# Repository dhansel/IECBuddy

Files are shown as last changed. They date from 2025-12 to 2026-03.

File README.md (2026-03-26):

# IECBuddy

IECBuddy is a USB plug-in for the [C64 RAD Expansion Unit](https://github.com/frntc/RAD), giving the RAD
access to the C64's IEC bus. The IECBuddy is based on my [IECDevice](https://github.com/dhansel/IECDevice)
and [VDrive](https://github.com/dhansel/VDrive) libraries, allowing the RAD to support various disk image 
formats (D64, G64, D71, D81) and fast-load protocols (JiffyDos, Epyx FastLoad, Final Cartridge 3, Action Replay 6,
DolphinDos and SpeedDos). Additionally, the IECBuddy acts as a virtual printer. Printed content can be viewed
on the C64 screen from within the RAD menu.

<br>
  <div align="center">
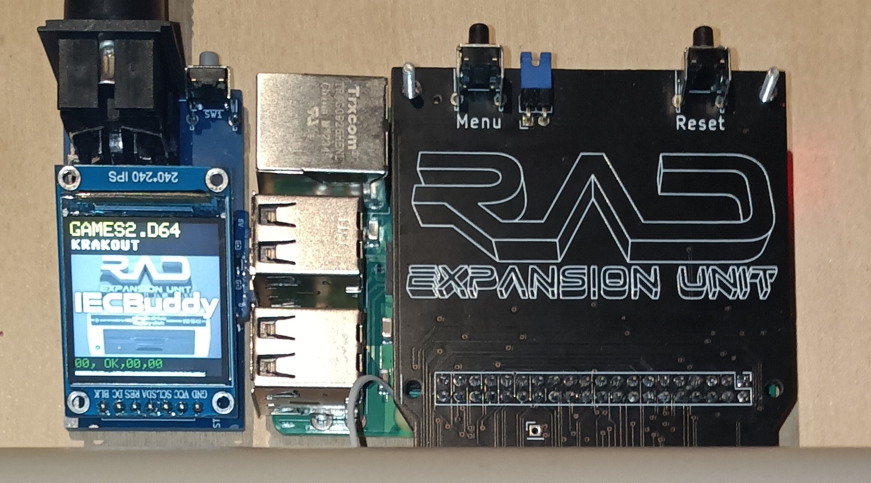
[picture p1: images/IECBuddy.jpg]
  
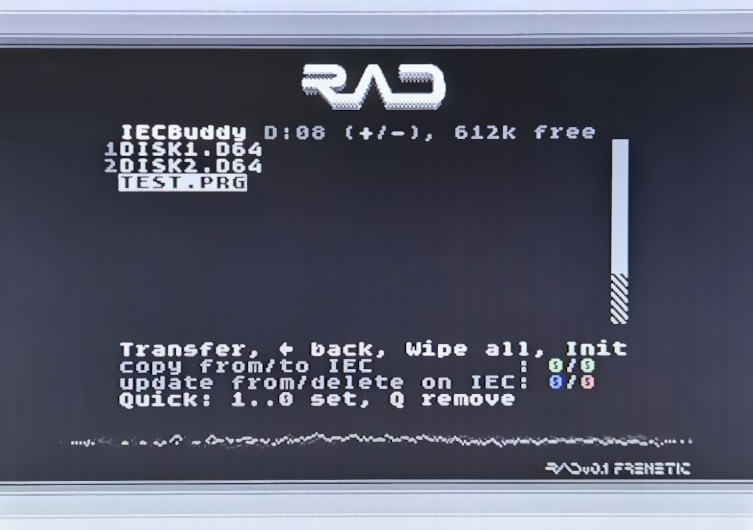
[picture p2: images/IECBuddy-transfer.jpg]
  
  </div>
<br>

The IECBuddy comes in four different variants, with differing amounts of components and build effort required:
  * [Barebones](IECBuddy-Barebones) (no PCB, use any RP2040/RP235x module)
  * [Micro](IECBuddy-Micro) (like Barebones but with a PCB and disk change button, requires a RP module pin-compatible with RP2040-One)
  * [Mini](IECBuddy-Mini) (like Micro but with a display and better bus interface, requires a RP module pin-compatible with RP2040-One)
  * [Max](IECBuddy-Max) (like Mini but with parallel cable connector, requires a RP module pin-compatible with Raspberry Pi Pico)

Of course a myriad versions of RP2040 and R235x modules exist. The PCBs for the IECBuddy Micro and Mini variants assume the pinout
of a [RP2040-One](https://www.amazon.com/RP2040-One-Pico-Like-Raspberry-Dual-Core-Processor/dp/B0BMM7SS99). The PCB for the
IECBuddy Max variant assumes the pinout of a Raspberry Pi Pico. The IECBuddy Barebones variant can work with any RP2040 or RP235x module.

To keep things a bit more succinct, in the folling "RP module" stands for "RP2040/RP235x module".

If you have a module with a pinout matching your preferred IECBuddy variant, first check if your module is listed in the UF2 table within the
[uploading the firmware](#uploading-the-firmware) section. If you cannot use one of the provided UF2 firmware files it should still
be fairly easy to [compile and upload](software/IECBuddy/README.md) the firmware yourself.

The IECBuddy stores files and disk images in the RP module's flash memory. One MB of flash memory is used for the
firmware itself, the remainder can be used for storing disk images. One MB of flash memory can hold about six D64 disk images.
Note that disk images can easily be transferred between the RAD and the IECBuddy so the IECBuddy does not need to hold all
your disk images at the same time.

The IECBuddy can plug directly into a RAD powered by a Raspberry Pi 3. If your RAD uses a Raspberry Pi Zero then 
you will need [an adapter cable](https://www.raspberrypi.com/products/micro-usb-male-to-usb-a-female-cable/) 
to connect the IECBuddy since the Zero only has a micro-USB OTG port.

To build an IECBuddy, select and build whichever variant appeals to you and then follow the instructions in the
[Uplodading the firmware](#uploading-the-firmware) section below.

## IECBuddy Barebones

The barebones variant is the simplest version, requiring no manufactured PCB. While the pictures shown here use
a [RP2040-One](https://www.amazon.com/RP2040-One-Pico-Like-Raspberry-Dual-Core-Processor/dp/B0BMM7SS99) module, any
RP module should work. Additionally you will need a Commodore [serial cable](https://www.c64-wiki.com/wiki/Serial_Port)
connector. Either solder the cable directly to the RP module or set it up on a breadboard:

<br>
  <div align="center">
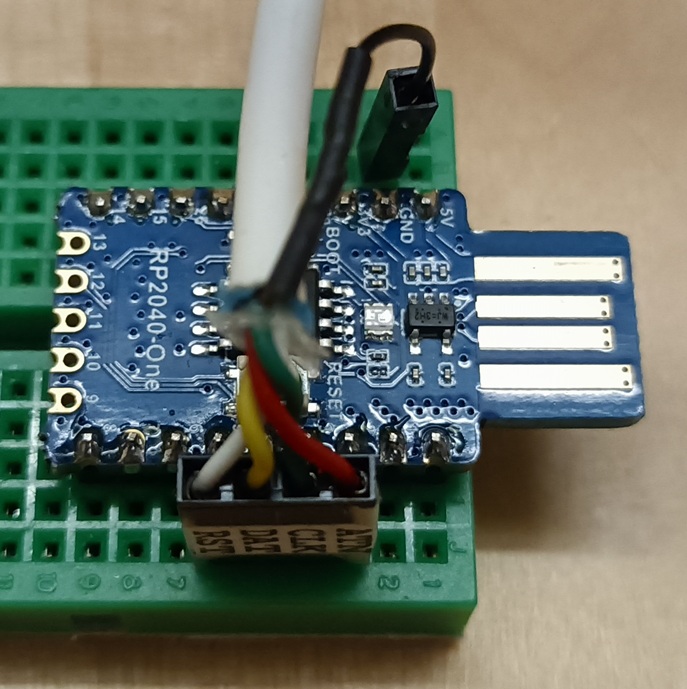
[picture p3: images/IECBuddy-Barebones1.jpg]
  
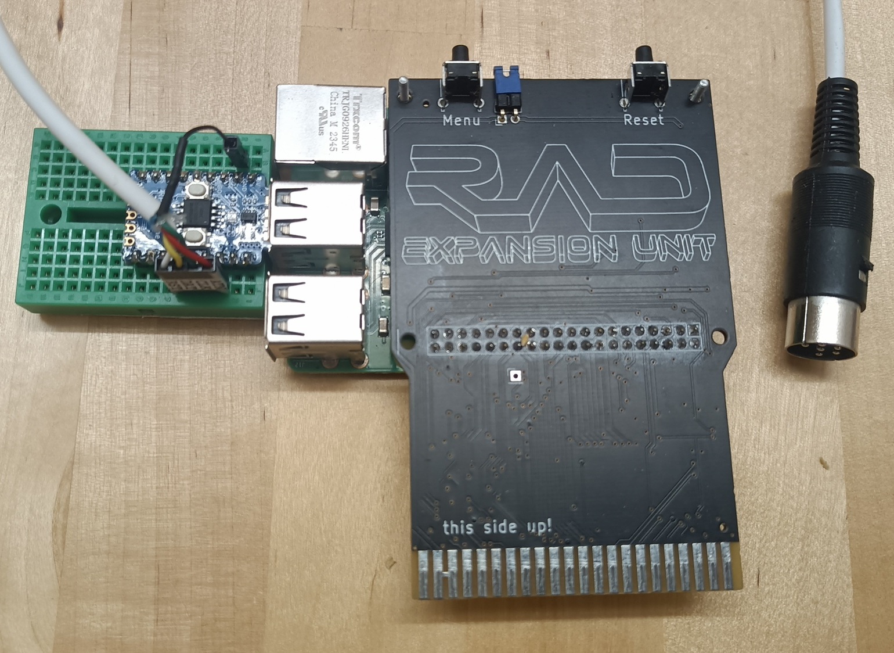
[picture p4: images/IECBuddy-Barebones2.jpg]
  
  </div>
<br>

Connect the Commodore serial cable to the RP module as follows:

IEC Bus Pin | Signal   | RP module
------------|----------|-----------
1           | SRQ      | Not connected 
2           | GND      | GND
3           | ATN      | GPIO2
4           | CLK      | GPIO3 
5           | DATA     | GPIO4 
6           | RESET    | GPIO5 

Then [upload the IECBuddy Micro firmware](#uploading-the-firmware) to the RP module and you're good to go.
Downsides are that there is no display and no "Disk Change" button.
If you would like a "Disk Change" button, simply wire a pushbutton switch between pins GND and GPIO8 on the RP module.

Note that this connects the 5V IEC bus lines directly to the RP module inputs. There are varying
opinions online on whether or not this can damage the RP and/or whether the RP is
capable of properly driving the IEC bus lines (especially when multiple devices are connected).
In my testing I have not had any problems, even with multiple other devices connected. YMMV.

If you would prefer proper voltage conversion and line drivers then use the "Mini" version below.

## IECBuddy Micro

<br>
  <div align="center">
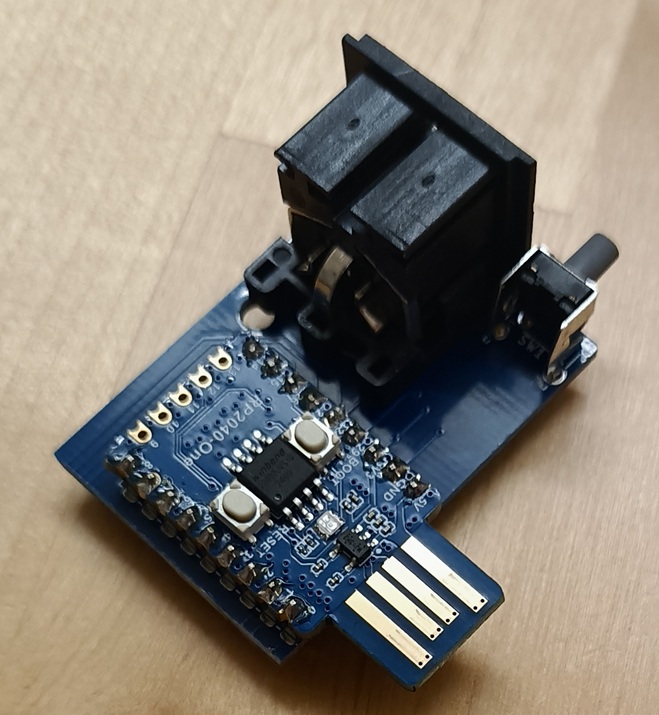
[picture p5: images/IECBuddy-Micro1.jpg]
  
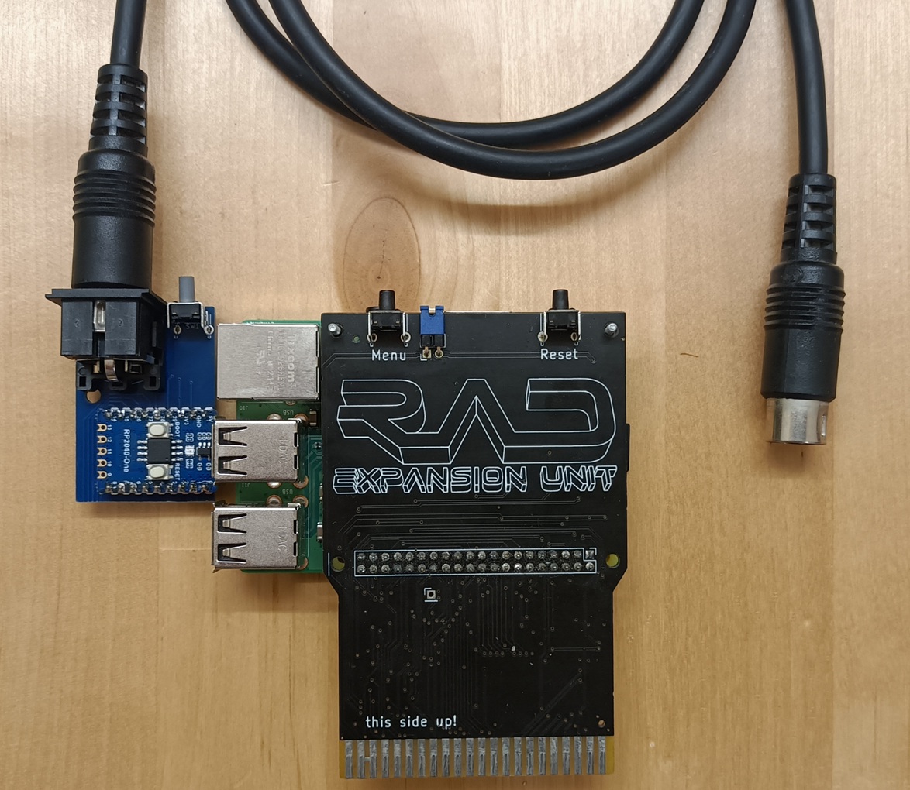
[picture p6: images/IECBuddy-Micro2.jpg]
  
  </div>
<br>

If you would like a somewhat cleaner and more permanent build but still want to go with a very small
footprint and minimal component count, use the "IECBuddy Micro" variant. This PCB requires a RP
module that is pin-compatible with the RP2040-One. Check the [Uplodading the firmware](#uploading-the-firmware) 
section below to see which RP modules are supported.

You can either solder the serial cable directly onto the board (connections are labeled on the board) or solder a 
proper IEC connector onto the board and use a standard serial cable. This also comes with
space for a pushbutton switch. No display though.

The same caveats regarding voltage conversion and line drivers apply as described in the "Barebones" section above.

A Gerber file for PCB production can be downloaded [here](https://github.com/dhansel/IECBuddy/raw/refs/heads/main/hardware/IECBuddy-micro-gerber.zip).<br>
A PDF file with the schematics is available [here](https://github.com/dhansel/IECBuddy/raw/refs/heads/main/hardware/IECBuddy-micro-schematic.pdf).<br>
KiCad files for the board are [here](hardware/IECBuddy-micro).

You will need the following components (the given links are just suggestions, I do not get any kickbacks for them).

Designator | Component 
-----------|-----------
U1         | [RP2040-One](https://www.amazon.com/RP2040-One-Pico-Like-Raspberry-Dual-Core-Processor/dp/B0BMM7SS99)
SW1        | [Pushbutton Switch](https://www.digikey.com/en/products/detail/c-k/PTS645VH58-2-LFS/1146783)
IEC1       | [IEC Bus Connector (6 Pin)](https://www.aliexpress.us/item/3256807108500271.html)

You can skip the IEC1 connector if you solder the serial cable directly to the board (connections on the board are labeled).

## IECBuddy Mini

  <div align="center">
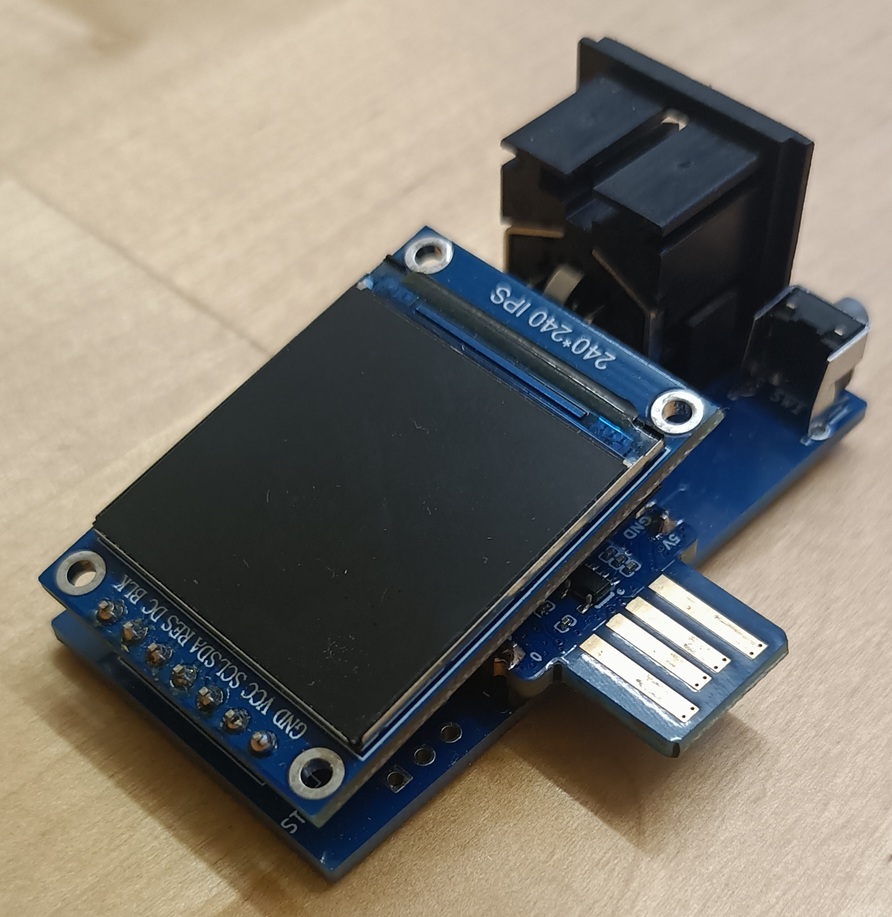
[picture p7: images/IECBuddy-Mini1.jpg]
  
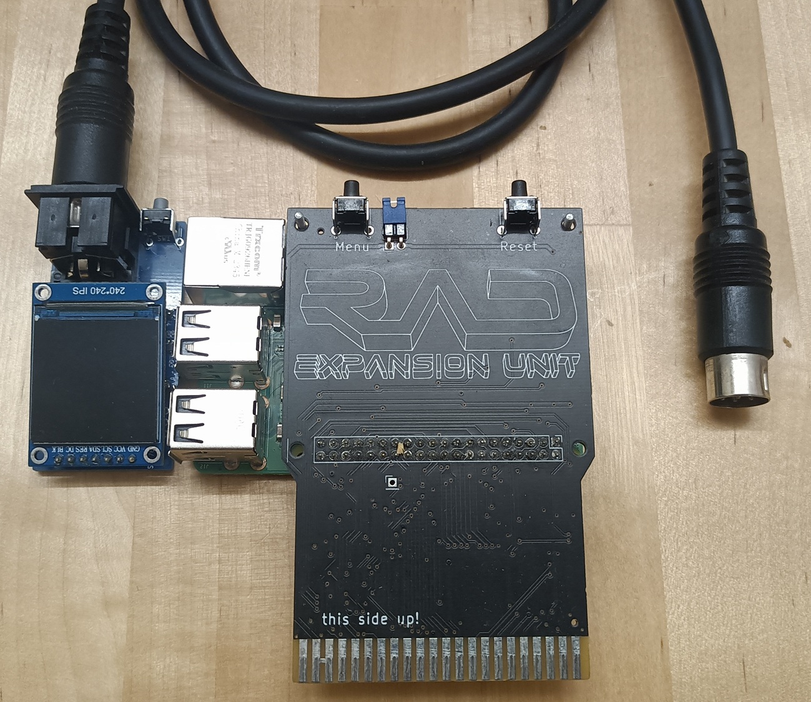
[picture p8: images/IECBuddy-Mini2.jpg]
  
  </div>

The Mini variant is slightly larger than the Micro version and requires more components besides
the RP module. As a result it comes with the following features that are not present in the smaller versions:

First, it has space and connections on the PCB for a [1.3" TFT display](https://www.aliexpress.us/item/3256805899270213.html).
The display shows the currently mounted disk image as well as disk status and progress bars while loading.

Second, it uses 7406 and 74LVC04 ICs for voltage conversion and properly interfacing with and driving the Commodore IEC bus lines.
This is very similar to the way original hardware (like the 1541) interfaces to the IEC bus. It also protects the RP
from the possible overcurrent and overvoltage conditions described in the "Barebones" section above.

Like the Micro variant, this PCB requires a RP module that is pin-compatible with the RP2040-One. 
Check the [Uplodading the firmware](#uploading-the-firmware) section below to see which RP modules are supported.

A Gerber file for PCB production can be downloaded [here](https://github.com/dhansel/IECBuddy/raw/refs/heads/main/hardware/IECBuddy-mini-gerber.zip).<br>
A PDF file with the schematics is available [here](https://github.com/dhansel/IECBuddy/raw/refs/heads/main/hardware/IECBuddy-mini-schematic.pdf).<br>
KiCad files for the board are [here](hardware/IECBuddy-mini).

You will need the following components (the given links are just suggestions, I do not get any kickbacks for them).

Designator | Component 
-----------|-----------
R1,R2,R3,R4| [Resistor 1kOhm SMD0805](https://www.digikey.com/en/products/detail/stackpole-electronics-inc/RMCF0805FT1K00/1760090)
C1,C2      | [Ceramic Capacitor 100nF SMD0805](https://www.digikey.com/en/products/detail/kyocera-avx/KGM21NR71H104KT/563505)
U1         | [RP2040-One](https://www.amazon.com/RP2040-One-Pico-Like-Raspberry-Dual-Core-Processor/dp/B0BMM7SS99)
U2         | [74LVC04AD SOIC](https://www.digikey.com/en/products/detail/nexperia-usa-inc/74LVC04AD-118/946673)
U3         | [7406DR SOIC](https://www.digikey.com/en/products/detail/texas-instruments/SN7406DR/276661)
SW1        | [Pushbutton Switch](https://www.digikey.com/en/products/detail/c-k/PTS645VH58-2-LFS/1146783)
ST7789     | [TFT Display](https://www.aliexpress.us/item/3256805899270213.html)
IEC1       | [IEC Bus Connector (6 Pin)](https://www.aliexpress.us/item/3256807108500271.html)

Various components can be left out if desired:
  * You can leave out the IEC1 connector if you solder the serial cable directly to the board (connections on the board are labeled).
  * You can leave out the ST7789 display if you don't want a display.
  * If you don't want to use the IEC bus driver ICs then you can place solder on the JP1-JP5 solder jumpers and leave out R1-R4, C1, C2, U2 and U3 (in this case use the IECBuddyMicro.uf2 firmware).

I recommend uploading the firmware **before** soldering on the display. The display sits on top of the RP module, which
makes accessing the "Boot" button (required for firmware upload) tricky - still possible, but a bit fiddly.

## IECBuddy Max

The IECBuddy Max variant has a much larger PCB layout and uses a Raspberry Pi Pico (version 1 or 2).
It has all the features of the Mini version and additionally a second IEC port for daisy-chaining 
and a connector for a parallel cable to be used with Dolphin Dos and Speed Dos.
Descriptions on how to make a compatible parallel cable and user port connector can be found in
various places over the internet, for example
[here](https://github.com/dhansel/IECDevice/tree/main/hardware#user-port-breakout-board),
[here](https://github.com/svenpetersen1965/1541-parallel-adapter-SpeedDOS)
or [here](https://github.com/FraEgg/commodore-1541-parallel-port-adapter-c64-c128-speeddos-dolphindos)

  <div align="center">
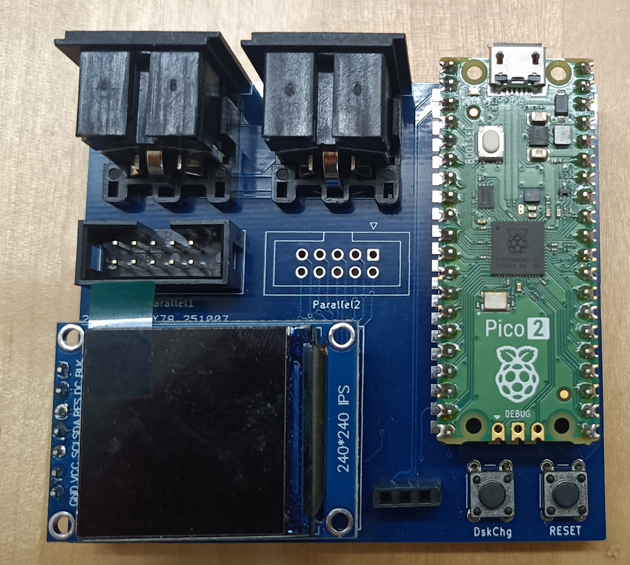
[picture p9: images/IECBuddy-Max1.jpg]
  
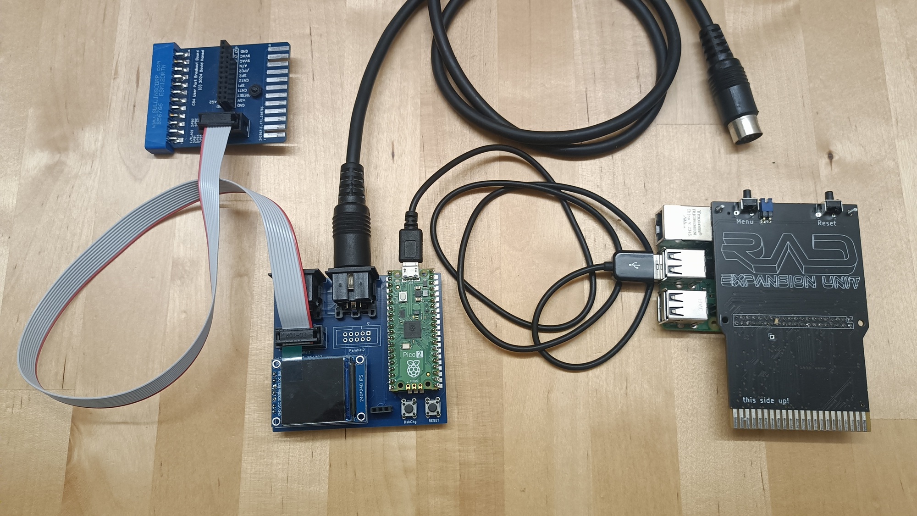
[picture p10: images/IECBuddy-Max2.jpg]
  
  </div>

A Gerber file for PCB production can be downloaded [here](https://github.com/dhansel/IECBuddy/raw/refs/heads/main/hardware/IECBuddy-max-gerber.zip).<br>
A PDF file with the schematics is available [here](https://github.com/dhansel/IECBuddy/raw/refs/heads/main/hardware/IECBuddy-max-schematic.pdf).<br>
KiCad files for the board are [here](hardware/IECBuddy-max).

This PCB requires a RP module that is pin-compatible with the Raspberry Pi Pico. 
Check the [Uplodading the firmware](#uploading-the-firmware) section below to see which RP modules are supported.

You will need the following components (the given links are just suggestions, I do not get any kickbacks for them).

Designator | Component 
-----------|-----------
R1,R2,R3,R4| [Resistor 1kOhm SMD0805](https://www.digikey.com/en/products/detail/stackpole-electronics-inc/RMCF0805FT1K00/1760090)
C1,C2,C3   | [Ceramic Capacitor 100nF SMD0805](https://www.digikey.com/en/products/detail/kyocera-avx/KGM21NR71H104KT/563505)
U1         | [Raspberry Pi Pico](https://www.microcenter.com/product/661033/raspberry-pi-pico-microcontroller-development-board)
U2         | [74CBTD3861DW](https://www.digikey.com/en/products/detail/texas-instruments/SN74CBTD3861DW/378015)
U3         | [74LVC04AD SOIC](https://www.digikey.com/en/products/detail/nexperia-usa-inc/74LVC04AD-118/946673)
U4         | [7406DR SOIC](https://www.digikey.com/en/products/detail/texas-instruments/SN7406DR/276661)
Reset,DiskChg | [Pushbutton Switch](https://www.digikey.com/en/products/detail/same-sky-formerly-cui-devices-/TS02-66-60-BK-100-LCR-D/15634327)
ST7789     | [TFT Display](https://www.aliexpress.us/item/3256805899270213.html)
IEC1       | [IEC Bus Connector (6 Pin)](https://www.aliexpress.us/item/3256807108500271.html)
Parallel1, Parallel2 | [10-position IDC Connector](https://www.digikey.com/en/products/detail/on-shore-technology-inc/302-S101/2178422)

## Uploading the firmware

Pre-compiled versions of the firmware are available for all four versions of the IECBuddy and a variety of RP modules. 

If your RP module is included in the table below then programming is trivial. First, download the UF2 file appropriate for your IECBuddy variant and RP module
("---" in the table means "not supported because the RP module does not match the PCB"):

IECBuddy   | [RP2040-One](https://www.amazon.com/RP2040-One-Pico-Like-Raspberry-Dual-Core-Processor/dp/B0BMM7SS99) <br> (4MB flash) | [RP2350-One](https://www.ebay.com/itm/286217752456) <br> (4MB flash) | [TENSTAR RP2350](https://aliexpress.com/item/1005008622261552.html) <br> (16MB flash) | Pi Pico <br> (2MB flash) | Pi Pico 2 <br> (4MB flash) | [Purple Pico](https://de.aliexpress.com/item/1005005594351599.html) <br> (16MB flash)
-----------|------------|------------|-------------------|----------------|---------------------|---------------------
Barebones  | [UF2](https://github.com/dhansel/IECBuddy/raw/refs/heads/main/software/IECBuddyMicro2040One.uf2) | [UF2](https://github.com/dhansel/IECBuddy/raw/refs/heads/main/software/IECBuddyMicro2350One.uf2) | [UF2](https://github.com/dhansel/IECBuddy/raw/refs/heads/main/software/IECBuddyMicroTenstar2350.uf2) | [UF2](https://github.com/dhansel/IECBuddy/raw/refs/heads/main/software/IECBuddyMicroPico1.uf2) | [UF2](https://github.com/dhansel/IECBuddy/raw/refs/heads/main/software/IECBuddyMicroPico2.uf2) | [UF2](https://github.com/dhansel/IECBuddy/raw/refs/heads/main/software/IECBuddyMicroPurplePico.uf2)
Micro      | [UF2](https://github.com/dhansel/IECBuddy/raw/refs/heads/main/software/IECBuddyMicro2040One.uf2) | [UF2](https://github.com/dhansel/IECBuddy/raw/refs/heads/main/software/IECBuddyMicro2350One.uf2) | [UF2](https://github.com/dhansel/IECBuddy/raw/refs/heads/main/software/IECBuddyMicroTenstar2350.uf2) | --- | --- | ---
Mini       | [UF2](https://github.com/dhansel/IECBuddy/raw/refs/heads/main/software/IECBuddyMini2040One.uf2) | [UF2](https://github.com/dhansel/IECBuddy/raw/refs/heads/main/software/IECBuddyMini2350One.uf2)  | [UF2](https://github.com/dhansel/IECBuddy/raw/refs/heads/main/software/IECBuddyMiniTenstar2350.uf2)  | --- | --- | ---
Max        | --- | --- | --- | [UF2](https://github.com/dhansel/IECBuddy/raw/refs/heads/main/software/IECBuddyMaxPico1.uf2) | [UF2](https://github.com/dhansel/IECBuddy/raw/refs/heads/main/software/IECBuddyMaxPico2.uf2) | ---

Then:
  1) Connect the USB connector of the RP module to your computer in "boot" mode. This can be done in two ways:
     - Make the connection to the computer **while holding down the "Boot" button on the device**. Note that this can be tricky
       for the Mini version if you have already soldered the display since the display obstructs access to the RP2040-One.
     - Just connect the RP module without holding the "Boot" button down. This will register a new serial (COM) port on your computer.
       Download [SKTool.exe](https://github.com/dhansel/IECBuddy/raw/refs/heads/main/software/SKTool/SKTool.exe) and run it with the following parameters: `SKTool -p COMx boot` (where COMx is the new COM port).
       Alternatively, start a terminal program (e.g. TeraTerm, Putty or even the serial monitor in the Arduino IDE) and connect
       to the new COM port with a baud rate of 1200.
     As a result of either of these, your computer should now show a new external drive.
  2) Copy the downloaded UF2 file to the root directory of the new drive.
  3) Disconnect the RP module from your computer.

If your RP module is not included in the table above and/or you would like to compile the firmware yourself, instructions can be found [here](software/IECBuddy/README.md). 

## Usage

When it is connected to the RAD (via USB) and C64 (via serial cable), the IECBuddy behaves like a disk drive.
The initial device number is 8 but can be configured from within the RAD menu system.

The IECBuddy is based on the [IECDevice library](https://github.com/dhansel/IECDevice) and therefore supports the 
same fastload protocols: JiffyDos, Epyx FastLoad, Final Cartridge 3, Action Replay 6, DolphinDos and SpeedDos.
Games that use their own fastload protocols will likely not work, the IECBuddy will report error "M-E not supported"
and the on-board LED will blink quickly (5Hz as opposed to 2Hz for a regular error).

Loading the directory shows all files and disk images currently on the IECBuddy file system. You can use "CD"
to enter and exit disk images. If you have a DOS wedge (like in JiffyDos), `@CD:GAMES.D64` will enter the GAMES.D64
Disk image, `@CD/` will exit the image and go back to the top-level directory. If you do not have a DOS wedge, 
doing a `LOAD"GAMES.D64",8` will automatically switch into the GAMES.D64 disk image and load its directory,
`LOAD"/",8` will return to the top level.

If desired, a new disk image can be created by using the "N" command, for examplem, executing `@N:GAMES2.D64`
in the top-level dierctory will create a new disk image named GAMES2.D64.

Files (either PRG files or disk images) can be copied between the IECBuddy and the RAD's SD card via the RAD menu system.
To enter the [IECBuddy submenu](https://github.com/frntc/RAD#iecbuddy-submenu) on the RAD, press "I" within the RAD main menu.

<br>
  <div align="center">
  
  </div>
<br>

The IECBuddy also emulates a printer, more specifically a STAR NL-10 printer with device number 4. The STAR NL-10 was
compatible with Commodore MPS-801 commands as well as the EPSON FX-80 command set. Much of the existing C64 software
supports either one of these (if not specifically the NL-10) and should therefore be compatible.

After printing, enter the RAD menu to see a preview of the printout and/or copy a BMP or PDF version of the printed
content to the RAD's SD card.

<br>
  <div align="center">
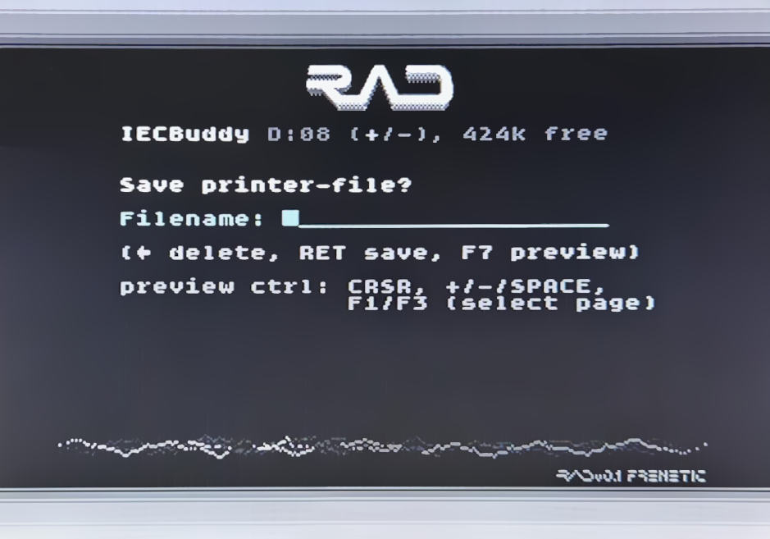
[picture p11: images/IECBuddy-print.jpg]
  
  </div>
<br>

For more information on the RAD menu structure relating to the IECBuddy see [here](https://github.com/frntc/RAD#iecbuddy-submenu).

As an alternative to copying files via the RAD menu interface you can use connect the IECBuddy to your PC 
and use [SKTool](software/SKTool) to manage the files directly.

## Firmware revisions

The following IECBuddy firmware revisions have been released:

  - **1.0** (January 26, 2026)
    - Initial release
   
  - **1.01** (March 16, 2026)
    - Support ",A" (append) file open mode in main directory
    - If a file is created in the main directory and the file has a known extension (PRG, SEQ, D64, D71, D81, G64, G71) then do not add an additional .PRG extension
    - Fixed JiffyDos protocol timing issue when transmitting EOI in single-byte protocol
    - Fixed support of "XF-" and "XF+" commands in DolphinDos

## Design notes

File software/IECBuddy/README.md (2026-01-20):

## Compiling the firmware from source

In most cases it is easiest to [simply upload the provided .uf2 files]([../../../README.md#uploading-the-firmware](https://github.com/dhansel/IECBuddy/tree/main?tab=readme-ov-file#uploading-the-firmware)) to the RP2040-One.

If you would like to compile the firmware from source then follow these steps:
  1) Download this GitHub repository.
  2) Load the "IECBuddy.ino" file from this directory in the Arduino IDE.
  3) In the Tools->Board menu, select the "Waveshare RP2040-One" board (or Raspberry Pi Pico 1 or 2 for the Max variant).
  4) In the Tools->Flash Size menu, select the following option:
     - For Waveshare RP2040-One or Raspberry Pi Pico 2: "4MB (Sketch 1MB, FS 3MB)"
     - For Raspberry Pi Pico 1: "2MB (Sketch 1MB, FS 1MB)"
     - If you are using a RP2040 clone with more flash then select the option that provides the most FS space possible, just leave 1MB for the sketch.
  6) Edit the "Pins.h" file to configure for your desired variant:
     - For the Barebones and Micro variants no changes are required
     - For the Mini or Max variants, un-comment the #defines for PIN_IEC_CLK_OUT and PIN_IEC_DATA_OUT
  7) If your build should support the ST7789 display then un-comment the PIN_ST7789_* defines. In that case you
    also need to make sure the "Adafruit GFX Library" is installed. You can compile in the display support even
    if you don't actually have a display.
  8) Plug in your RP2040-One or Pi Pico board and click the "upload" button in the Arduino IDE.

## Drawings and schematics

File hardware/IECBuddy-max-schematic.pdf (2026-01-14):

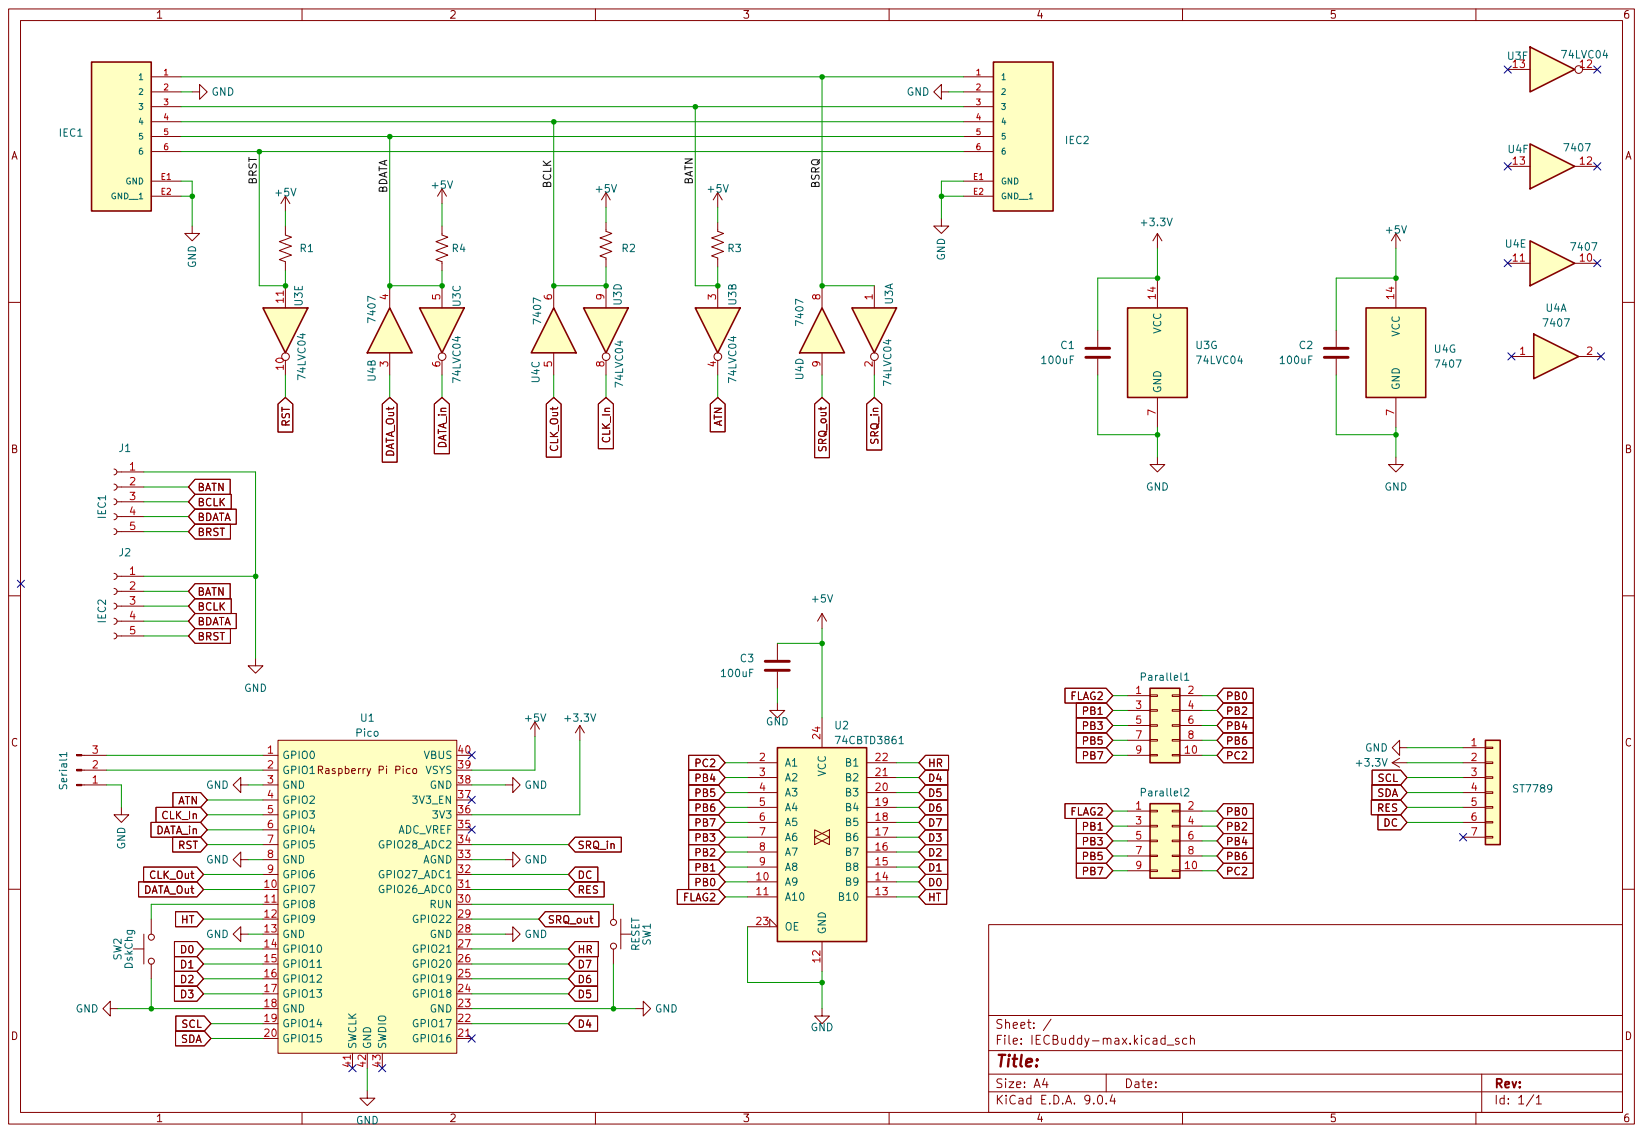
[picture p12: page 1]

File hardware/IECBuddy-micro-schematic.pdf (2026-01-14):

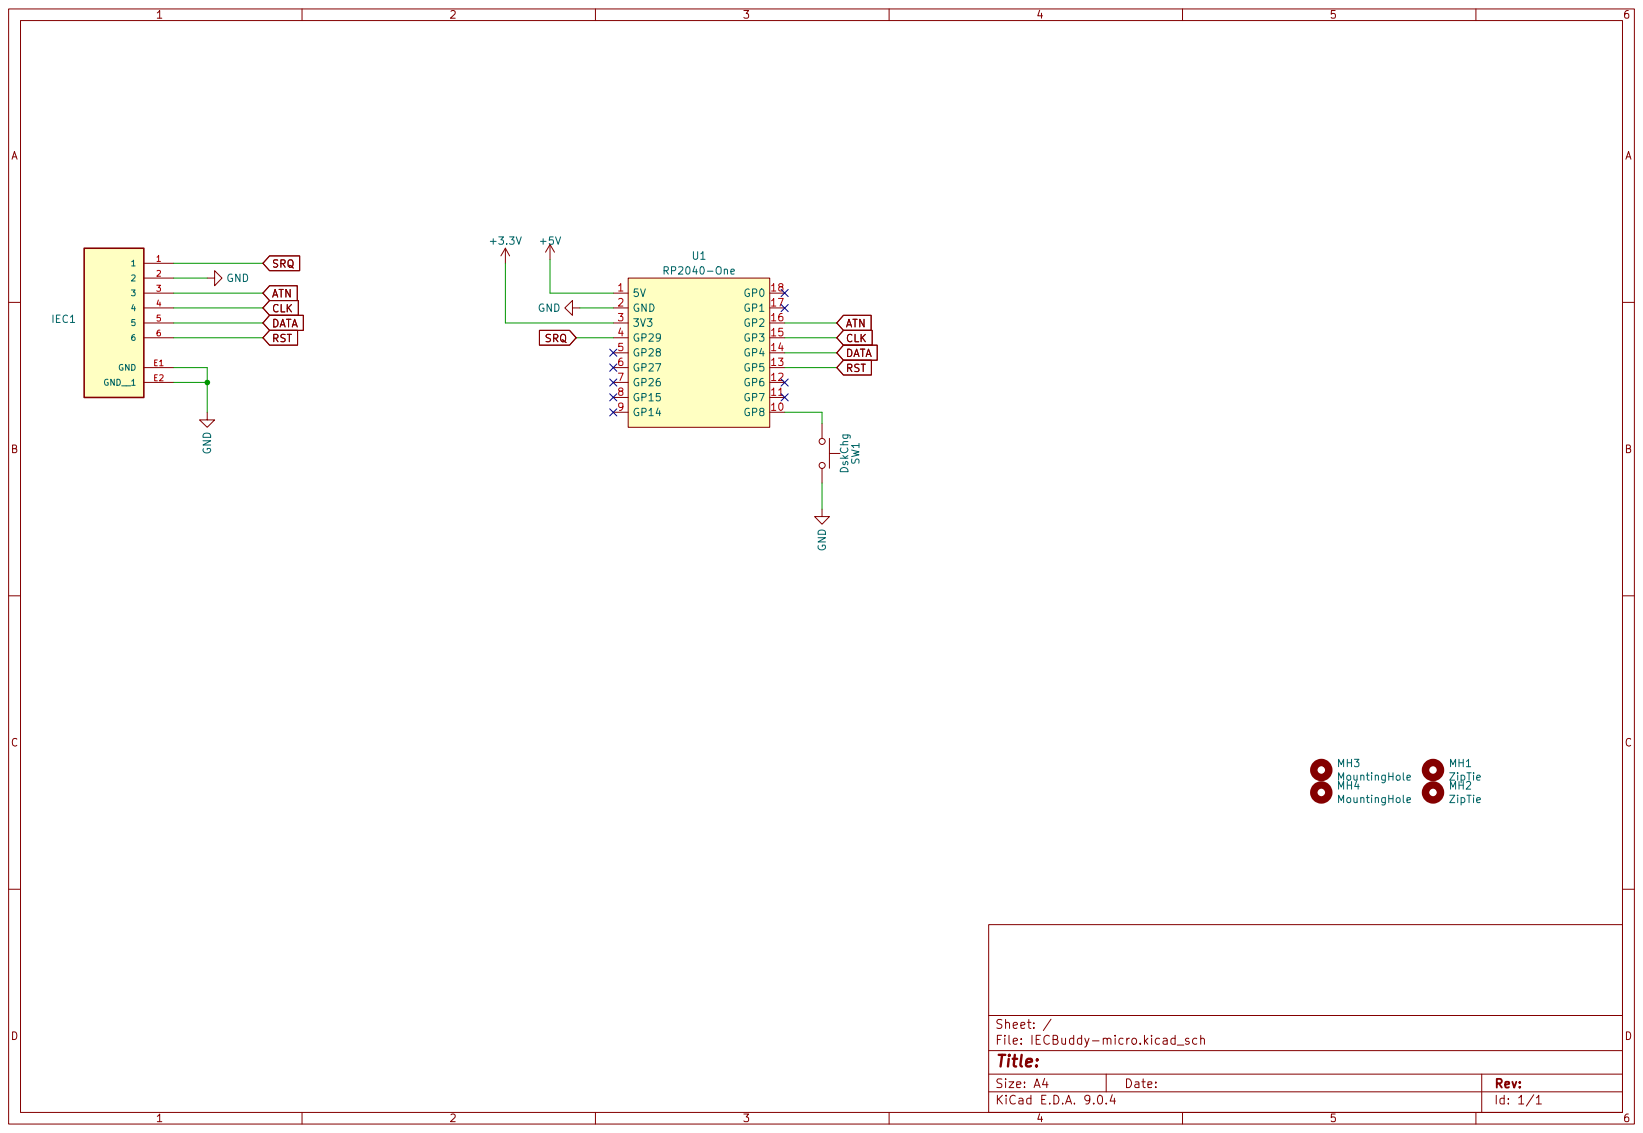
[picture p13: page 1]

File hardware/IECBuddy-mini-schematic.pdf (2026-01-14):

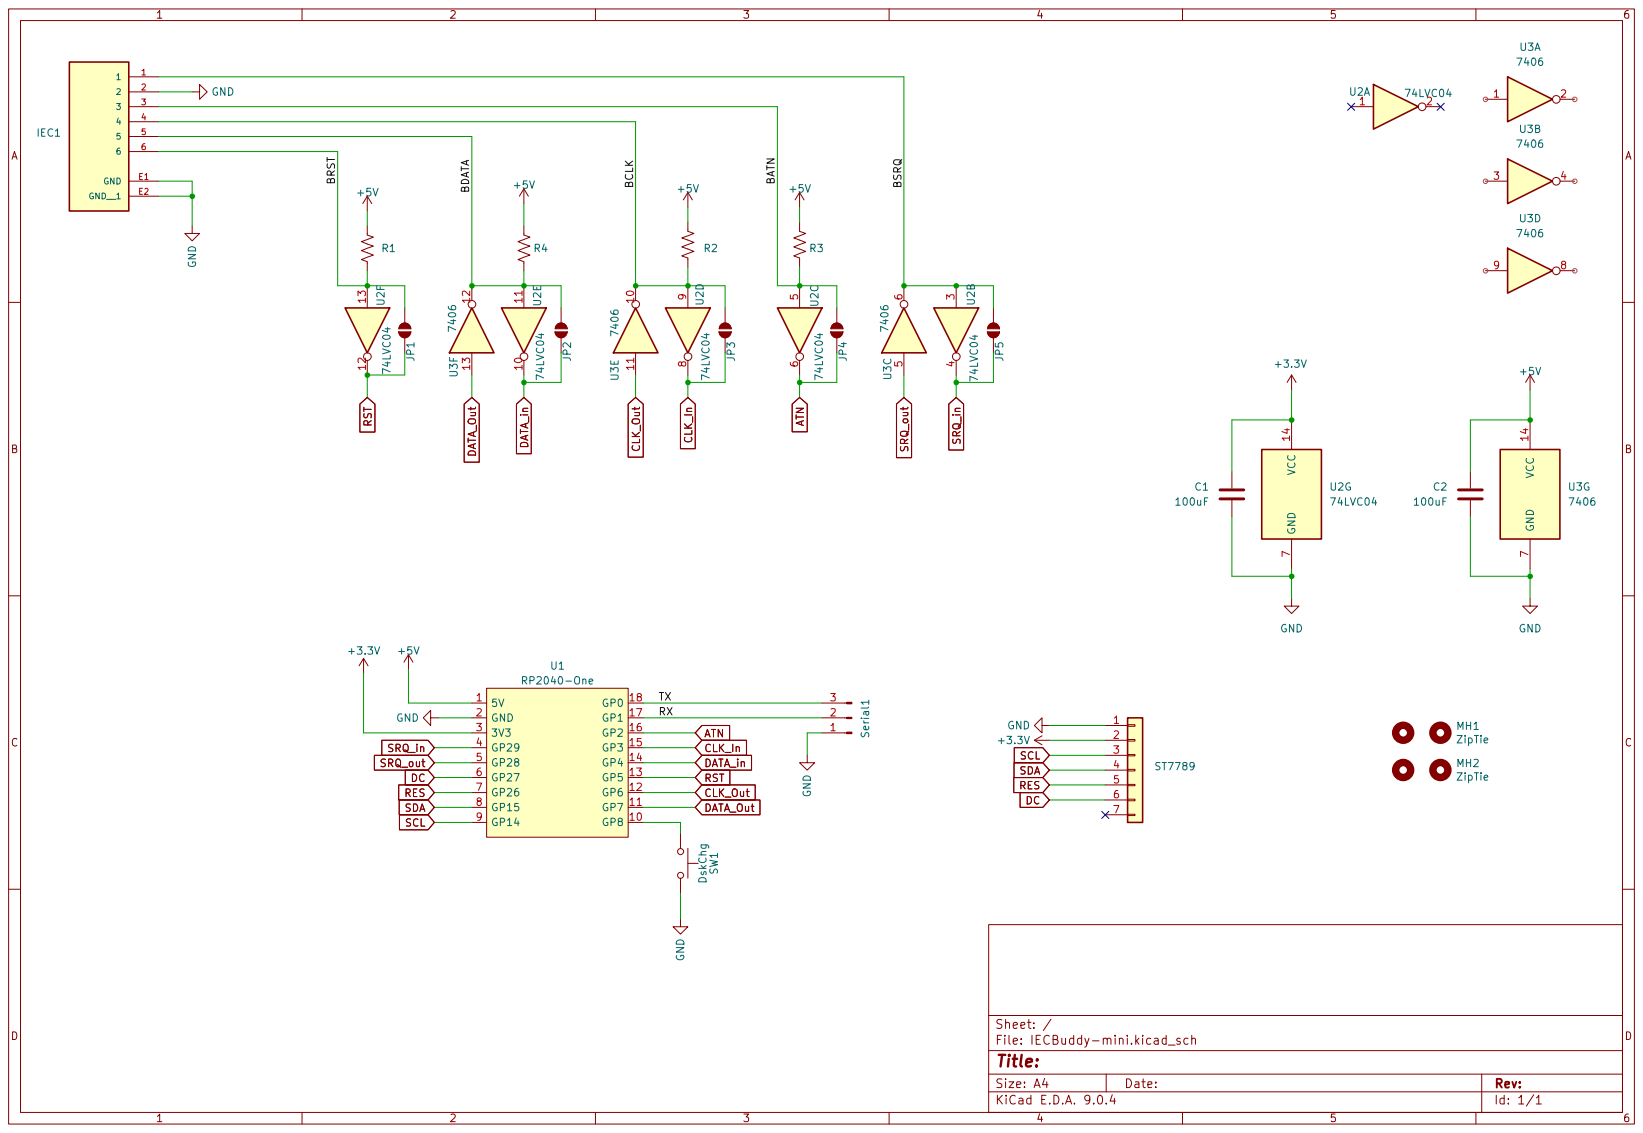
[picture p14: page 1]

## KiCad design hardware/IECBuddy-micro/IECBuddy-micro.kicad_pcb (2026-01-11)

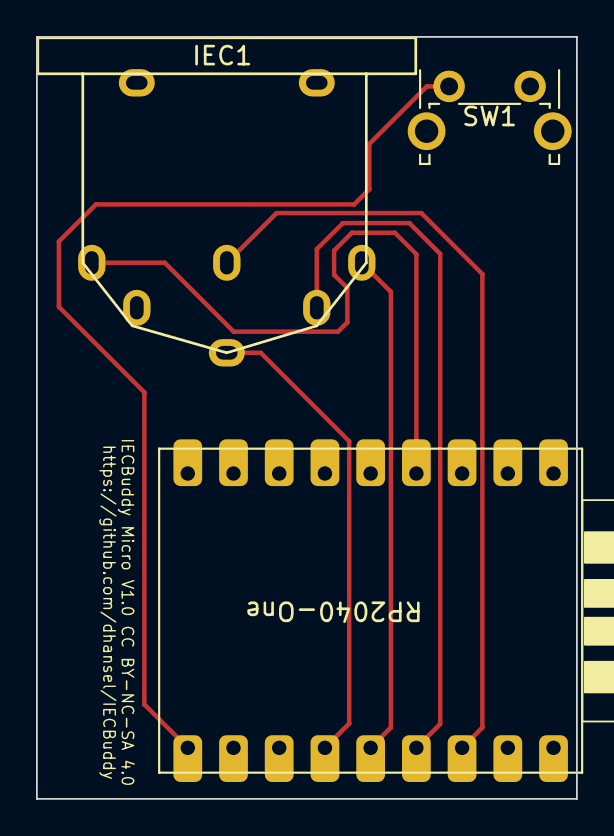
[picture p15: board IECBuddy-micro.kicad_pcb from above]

Board: 2 copper layers, 30.0 x 42.3 mm, 5 parts (0 on the bottom side), 7 nets.

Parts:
IEC1: SDS-60J; C64_IEC
MH1, MH2: ZipTie; ZipTie_3.0mm
SW1: DskChg; SW_Tactile_SPST_Angled_PTS645Vx83-2LFS
U1: RP2040-One; RP2040-One-Sidesonly

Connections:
ATN: IEC1.3, U1.16 (GP2)
CLK: IEC1.4, U1.15 (GP3)
DATA: IEC1.5, U1.14 (GP4)
GND: IEC1.2, IEC1.E1 (GND), IEC1.E2 (GND__1), SW1.2, U1.2 (GND)
unnamed: SW1.1, U1.10 (GP8)
RST: IEC1.6, U1.13 (GP5)
SRQ: IEC1.1, U1.4 (GP29)

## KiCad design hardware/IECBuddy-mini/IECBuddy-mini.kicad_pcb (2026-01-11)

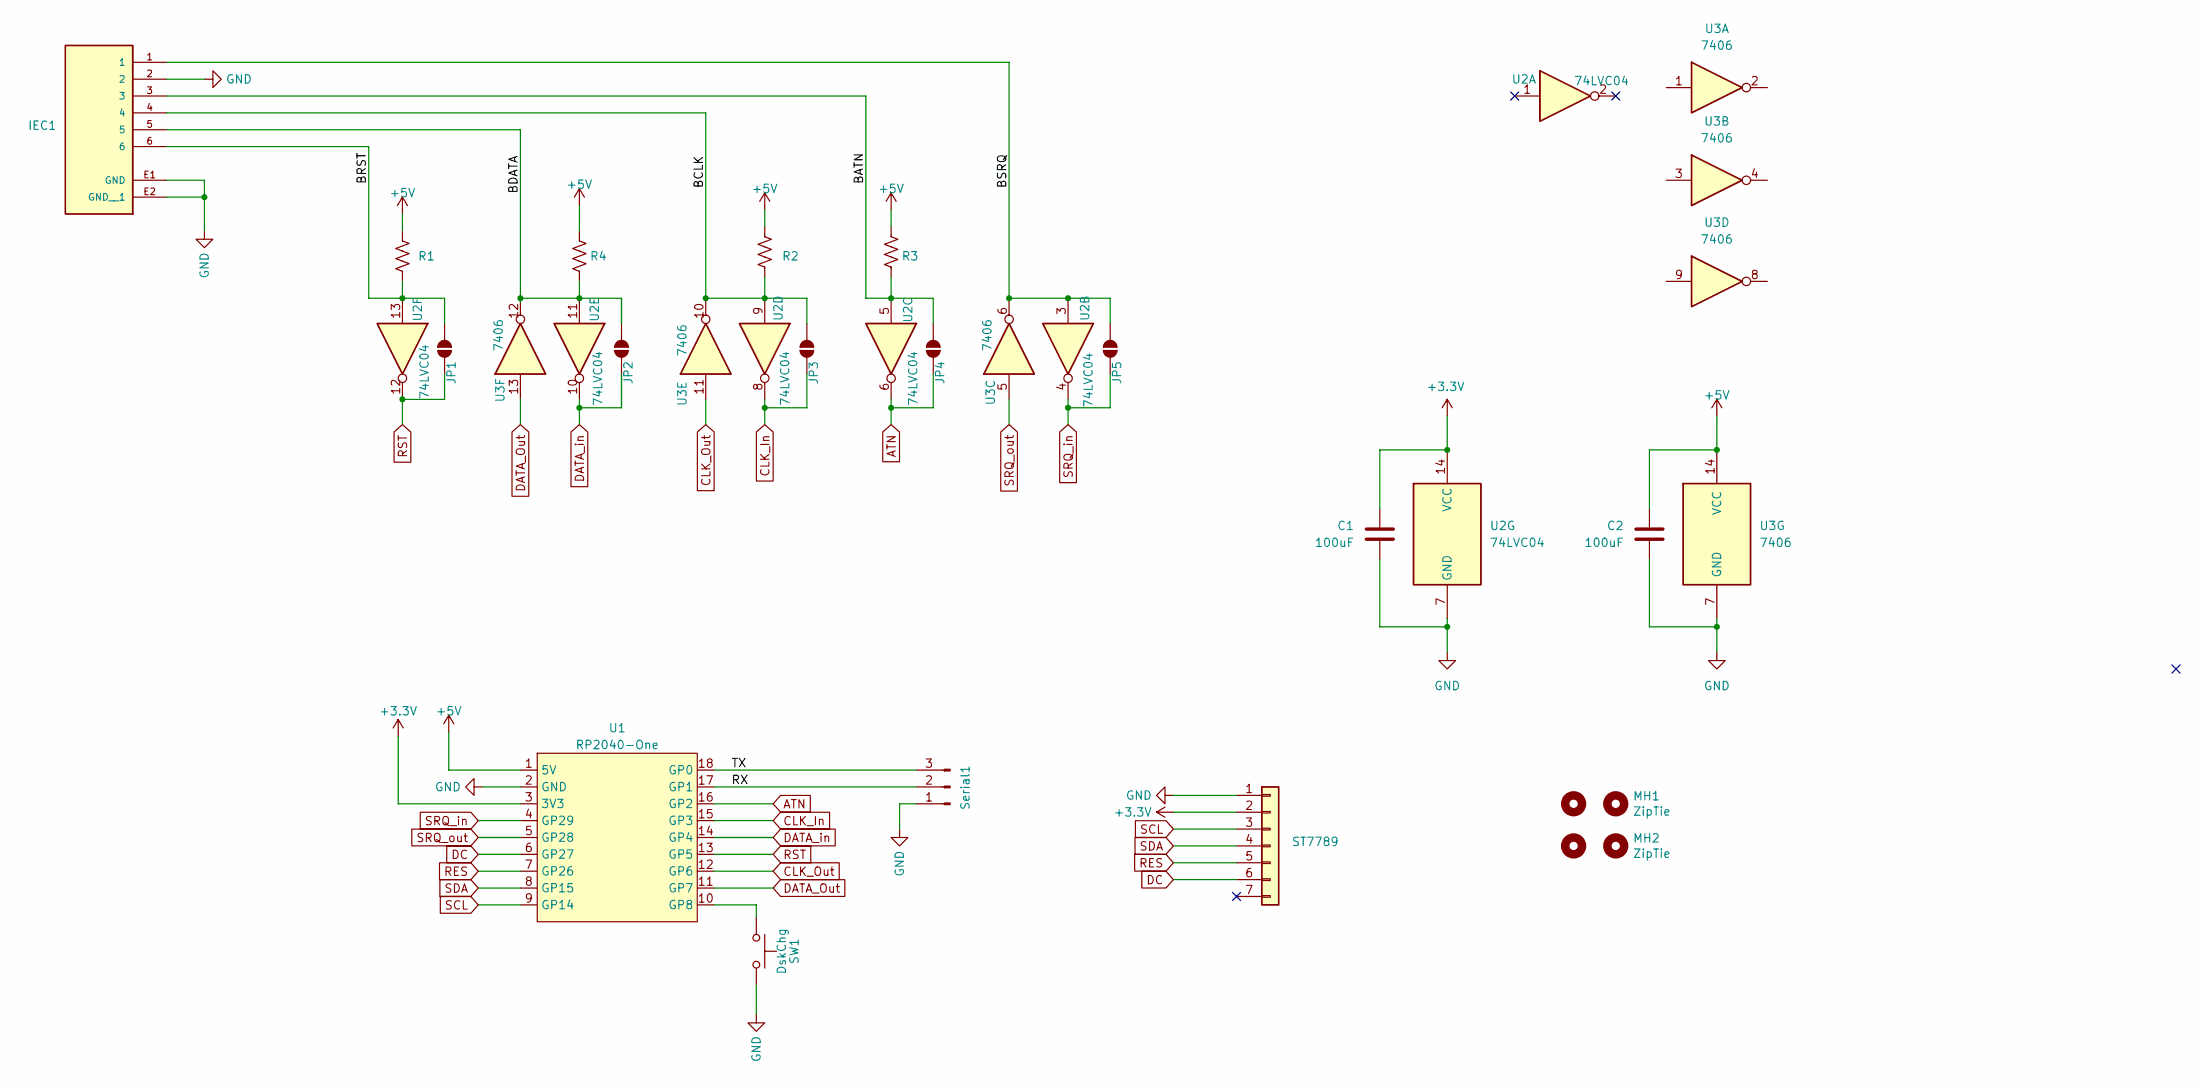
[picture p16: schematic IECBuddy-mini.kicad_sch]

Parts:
C1, C2: 100uF; C_0805_2012Metric_Pad1.18x1.45mm_HandSolder
H1, H2: MountingHole; MountingHole_3.2mm_M3
IEC1: SDS-60J; C64_IEC; PARTREV 1.06/02-13-2020
JP1, JP2, JP3, JP4, JP5: SolderJumper_2_Open; SolderJumper-2_P1.3mm_Open_Pad1.0x1.5mm
MH1, MH2: ZipTie; ZipTie_3.0mm
R1, R2, R3, R4: 1k; R_0805_2012Metric
ST7789: ST7789; PinHeader_1x07_P2.54mm_Vertical
SW1: DskChg; SW_Tactile_SPST_Angled_PTS645Vx83-2LFS
Serial1: Serial1; PinSocket_1x03_P2.54mm_Vertical
U1: RP2040-One; RP2040-One-Sidesonly
U2: 74LVC04; SOIC-14_3.9x8.7mm_P1.27mm
U3: 7406; SOIC-14_3.9x8.7mm_P1.27mm

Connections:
+3.3V: C1.1, ST7789.2, U1.3 (3V3), U2.14 (VCC)
+5V: C2.1, R1.1, R2.1, R3.1, R4.1, U1.1 (5V), U3.14 (VCC)
/BATN: IEC1.3, JP4.2 (B), R3.2, U2.5
/BCLK: IEC1.4, JP3.2 (B), R2.2, U2.9, U3.10
/BDATA: IEC1.5, JP2.2 (B), R4.2, U2.11, U3.12
/BRST: IEC1.6, JP1.2 (B), R1.2, U2.13
/BSRQ: IEC1.1, JP5.2 (B), U2.3, U3.6
/RX: Serial1.2, U1.17 (GP1)
/TX: Serial1.3, U1.18 (GP0)
ATN: JP4.1 (A), U1.16 (GP2), U2.6
CLK_In: JP3.1 (A), U1.15 (GP3), U2.8
CLK_Out: U1.12 (GP6), U3.11
DATA_Out: U1.11 (GP7), U3.13
DATA_in: JP2.1 (A), U1.14 (GP4), U2.10
DC: ST7789.6, U1.6 (GP27)
GND: C1.2, C2.2, IEC1.2, IEC1.E1 (GND), IEC1.E2 (GND__1), ST7789.1, SW1.2, Serial1.1, U1.2 (GND), U2.7 (GND), U3.7 (GND)
unnamed: SW1.1, U1.10 (GP8)
RES: ST7789.5, U1.7 (GP26)
RST: JP1.1 (A), U1.13 (GP5), U2.12
SCL: ST7789.3, U1.9 (GP14)
SDA: ST7789.4, U1.8 (GP15)
SRQ_in: JP5.1 (A), U1.4 (GP29), U2.4
SRQ_out: U1.5 (GP28), U3.5

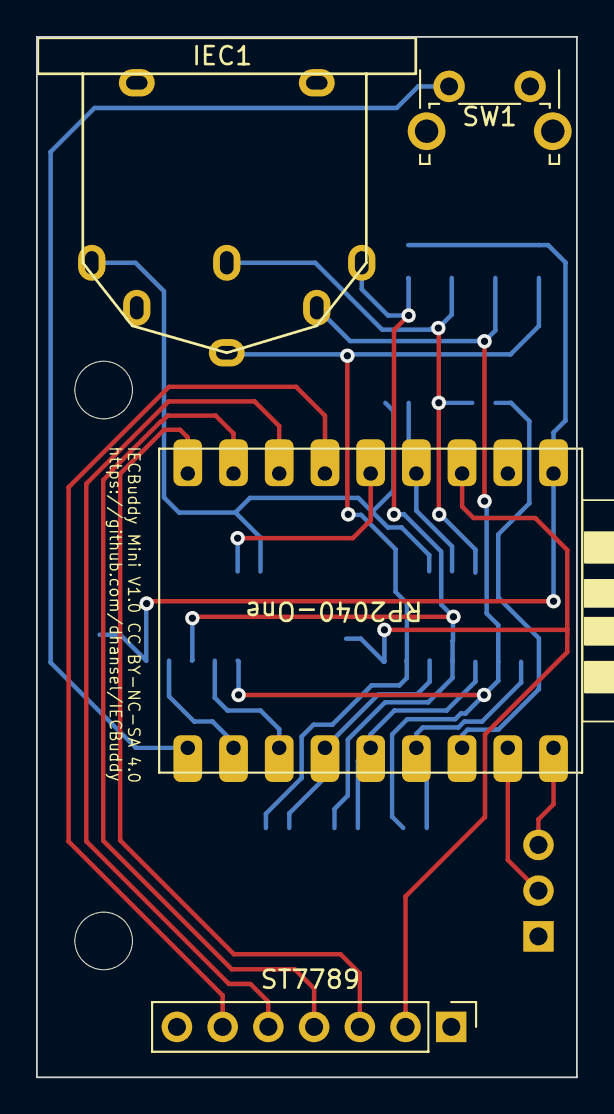
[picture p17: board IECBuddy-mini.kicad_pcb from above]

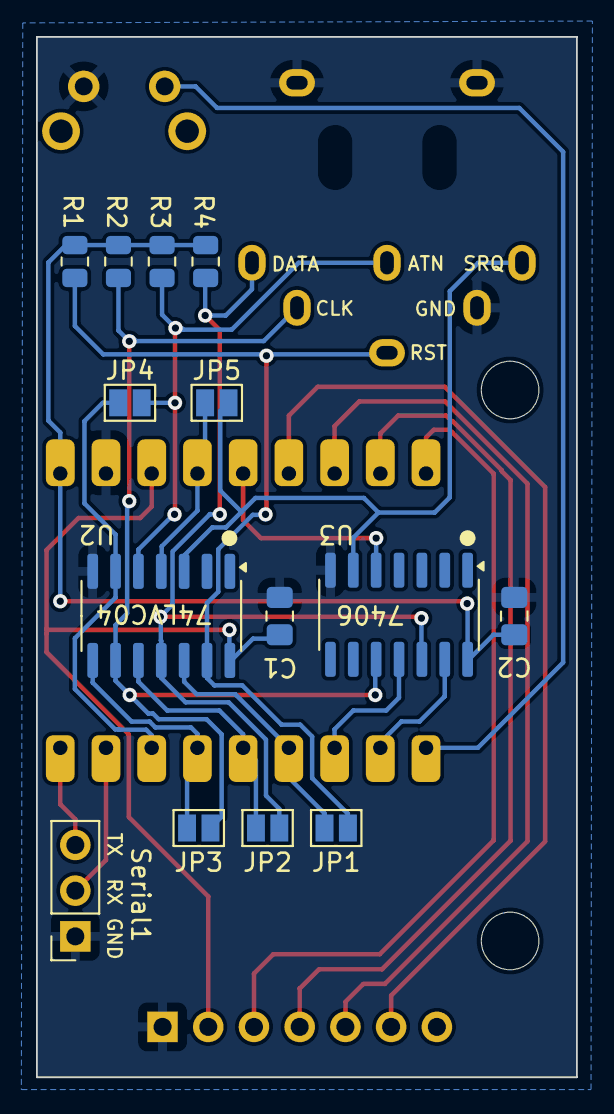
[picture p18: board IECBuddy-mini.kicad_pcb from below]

Board: 2 copper layers, 30.0 x 57.8 mm, 22 parts (14 on the bottom side), 23 nets.

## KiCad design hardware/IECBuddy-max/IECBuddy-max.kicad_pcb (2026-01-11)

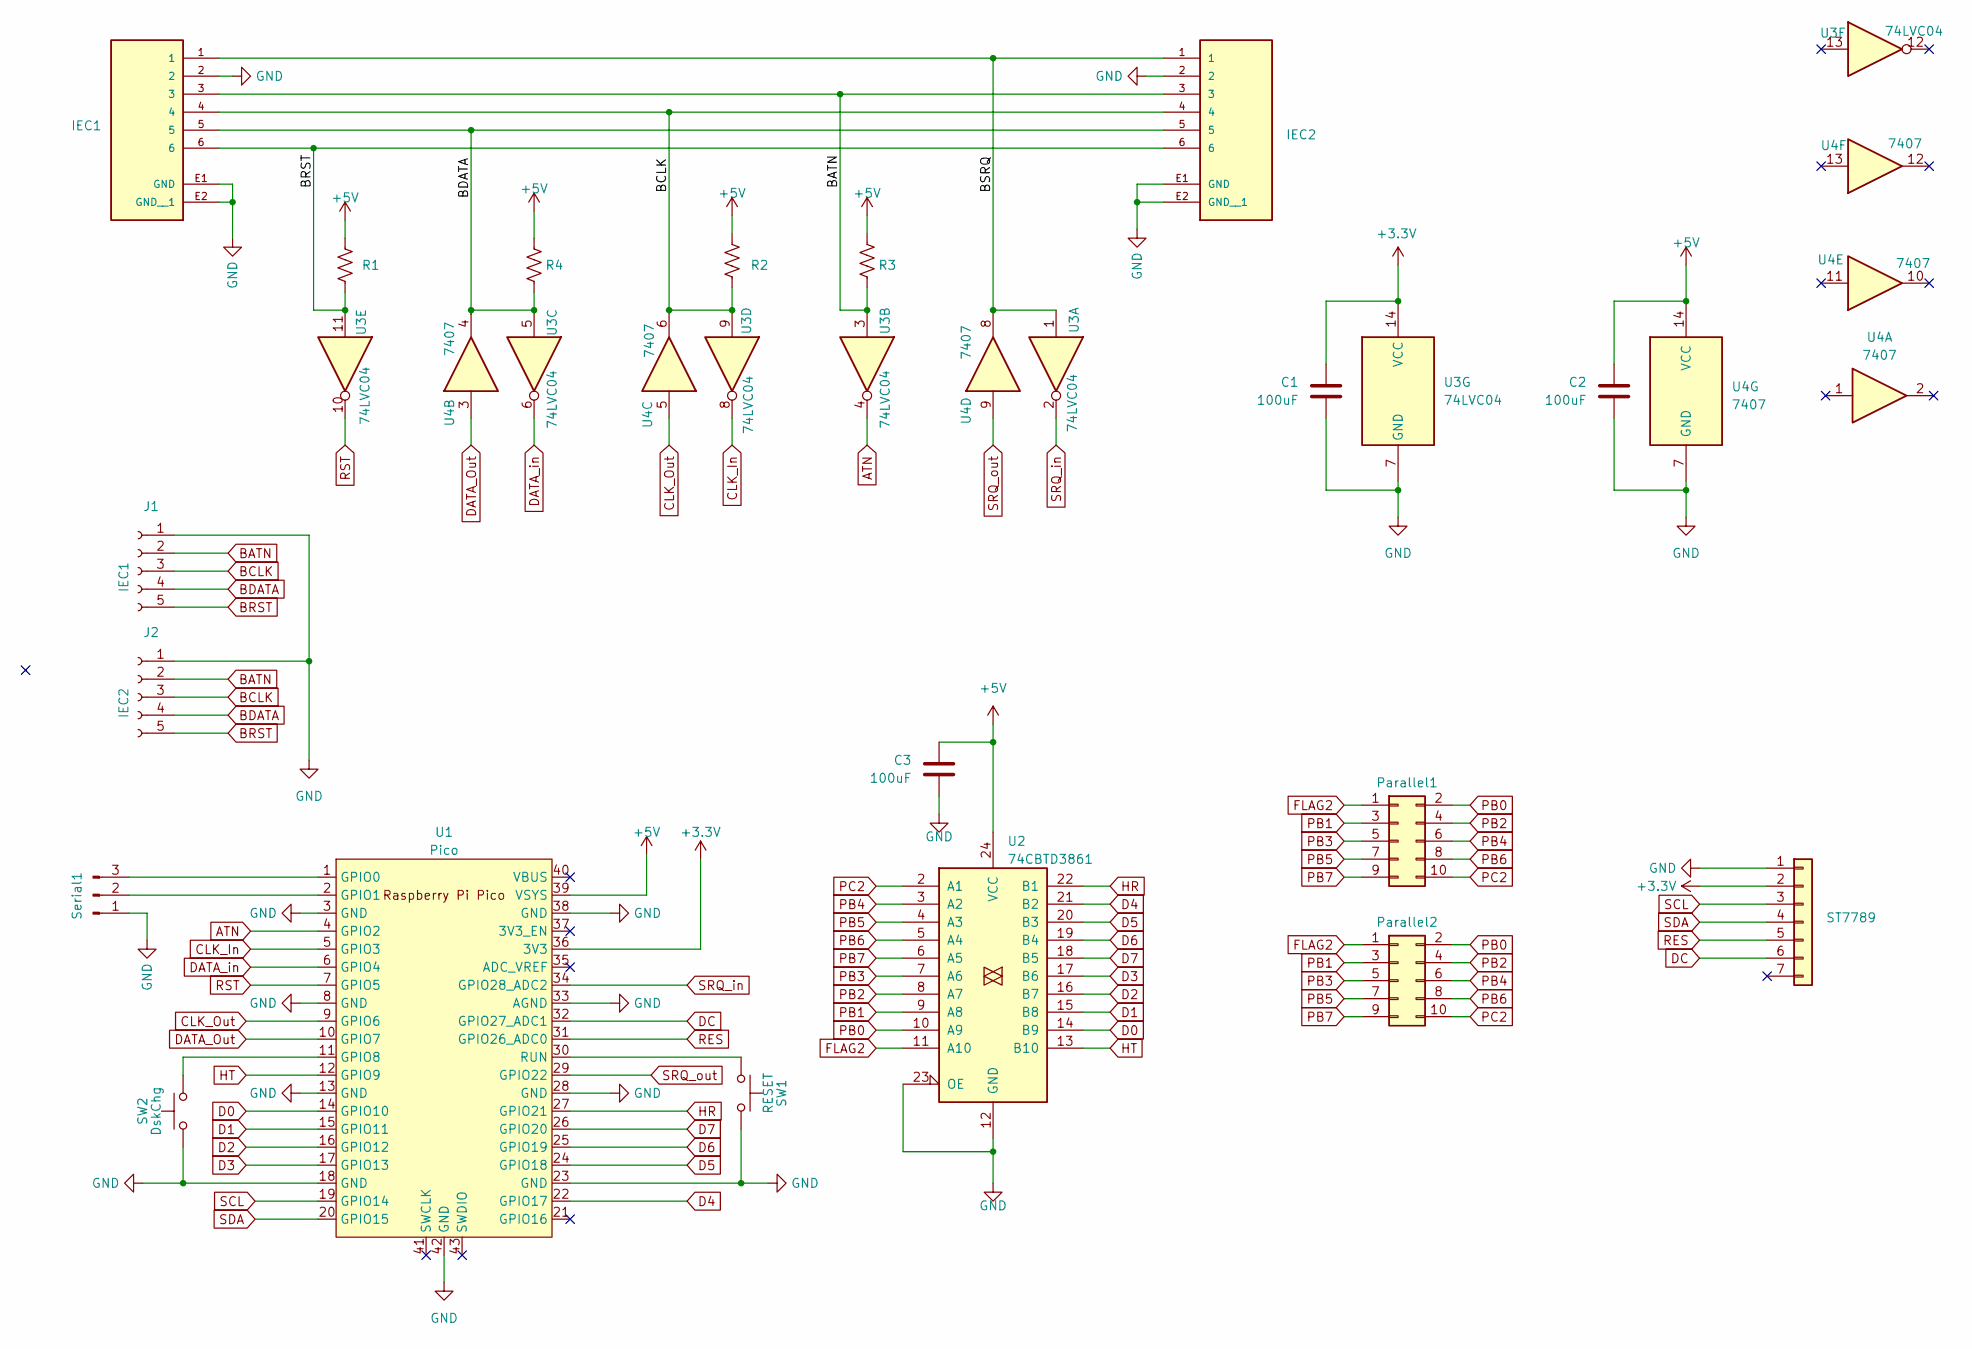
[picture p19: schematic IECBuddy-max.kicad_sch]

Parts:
C1, C2, C3: 100uF; C_0805_2012Metric_Pad1.18x1.45mm_HandSolder
IEC1, IEC2: SDS-60J; C64_IEC; PARTREV 1.06/02-13-2020
J1: IEC1; PinHeader_1x05_P2.54mm_Vertical
J2: IEC2; PinHeader_1x05_P2.54mm_Vertical
Parallel1: Parallel1; IDC-Header_2x05_P2.54mm_Vertical
Parallel2: Parallel2; IDC-Header_2x05_P2.54mm_Vertical
R1, R2, R3, R4: 1k; R_0805_2012Metric
ST7789: ST7789; PinHeader_1x07_P2.54mm_Vertical
SW1: RESET; SW_PUSH_6mm
SW2: DskChg; SW_PUSH_6mm
Serial1: Serial1; PinSocket_1x03_P2.54mm_Vertical
U1: Pico; RPi_Pico_SMD_TH
U2: 74CBTD3861; SOIC-24W_7.5x15.4mm_P1.27mm
U3: 74LVC04; SOIC-14_3.9x8.7mm_P1.27mm
U4: 7407; SOIC-14_3.9x8.7mm_P1.27mm

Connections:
+3.3V: C1.1, ST7789.2, U1.36 (3V3), U3.14 (VCC)
+5V: C2.1, C3.1, R1.1, R2.1, R3.1, R4.1, U1.39 (VSYS), U2.24 (VCC), U4.14 (VCC)
/BSRQ: IEC1.1, IEC2.1, U3.1, U4.8
ATN: U1.4 (GPIO2), U3.4
BATN: IEC1.3, IEC2.3, J1.2, J2.2, R3.2, U3.3
BCLK: IEC1.4, IEC2.4, J1.3, J2.3, R2.2, U3.9, U4.6
BDATA: IEC1.5, IEC2.5, J1.4, J2.4, R4.2, U3.5, U4.4
BRST: IEC1.6, IEC2.6, J1.5, J2.5, R1.2, U3.11
CLK_In: U1.5 (GPIO3), U3.8
CLK_Out: U1.9 (GPIO6), U4.5
D0: U1.14 (GPIO10), U2.14 (B9)
D1: U1.15 (GPIO11), U2.15 (B8)
D2: U1.16 (GPIO12), U2.16 (B7)
D3: U1.17 (GPIO13), U2.17 (B6)
D4: U1.22 (GPIO17), U2.21 (B2)
D5: U1.24 (GPIO18), U2.20 (B3)
D6: U1.25 (GPIO19), U2.19 (B4)
D7: U1.26 (GPIO20), U2.18 (B5)
DATA_Out: U1.10 (GPIO7), U4.3
DATA_in: U1.6 (GPIO4), U3.6
DC: ST7789.6, U1.32 (GPIO27_ADC1)
FLAG2: Parallel1.1, Parallel2.1, U2.11 (A10)
HR: U1.27 (GPIO21), U2.22 (B1)
HT: U1.12 (GPIO9), U2.13 (B10)
unnamed: Serial1.2, U1.2 (GPIO1)
unnamed: Serial1.3, U1.1 (GPIO0)
unnamed: SW2.2, U1.11 (GPIO8)
PB0: Parallel1.2, Parallel2.2, U2.10 (A9)
PB1: Parallel1.3, Parallel2.3, U2.9 (A8)
PB2: Parallel1.4, Parallel2.4, U2.8 (A7)
PB3: Parallel1.5, Parallel2.5, U2.7 (A6)
PB4: Parallel1.6, Parallel2.6, U2.3 (A2)
PB5: Parallel1.7, Parallel2.7, U2.4 (A3)
PB6: Parallel1.8, Parallel2.8, U2.5 (A4)
PB7: Parallel1.9, Parallel2.9, U2.6 (A5)
PC2: Parallel1.10, Parallel2.10, U2.2 (A1)
RES: ST7789.5, U1.31 (GPIO26_ADC0)
RST: U1.7 (GPIO5), U3.10
SCL: ST7789.3, U1.19 (GPIO14)
SDA: ST7789.4, U1.20 (GPIO15)
SRQ_in: U1.34 (GPIO28_ADC2), U3.2
SRQ_out: U1.29 (GPIO22), U4.9

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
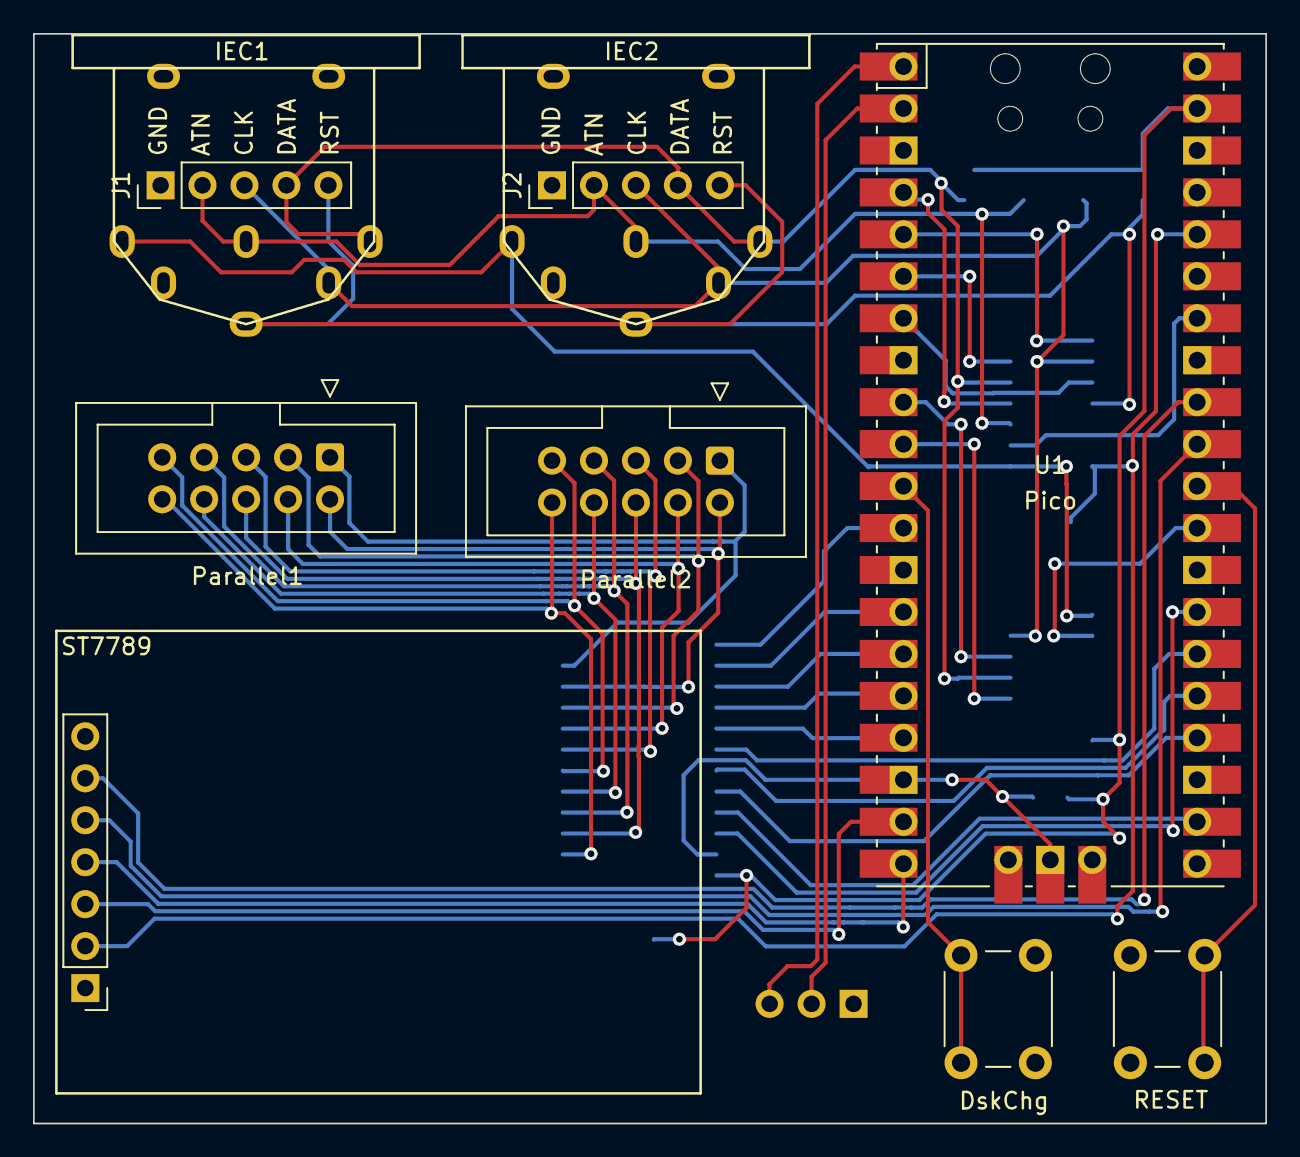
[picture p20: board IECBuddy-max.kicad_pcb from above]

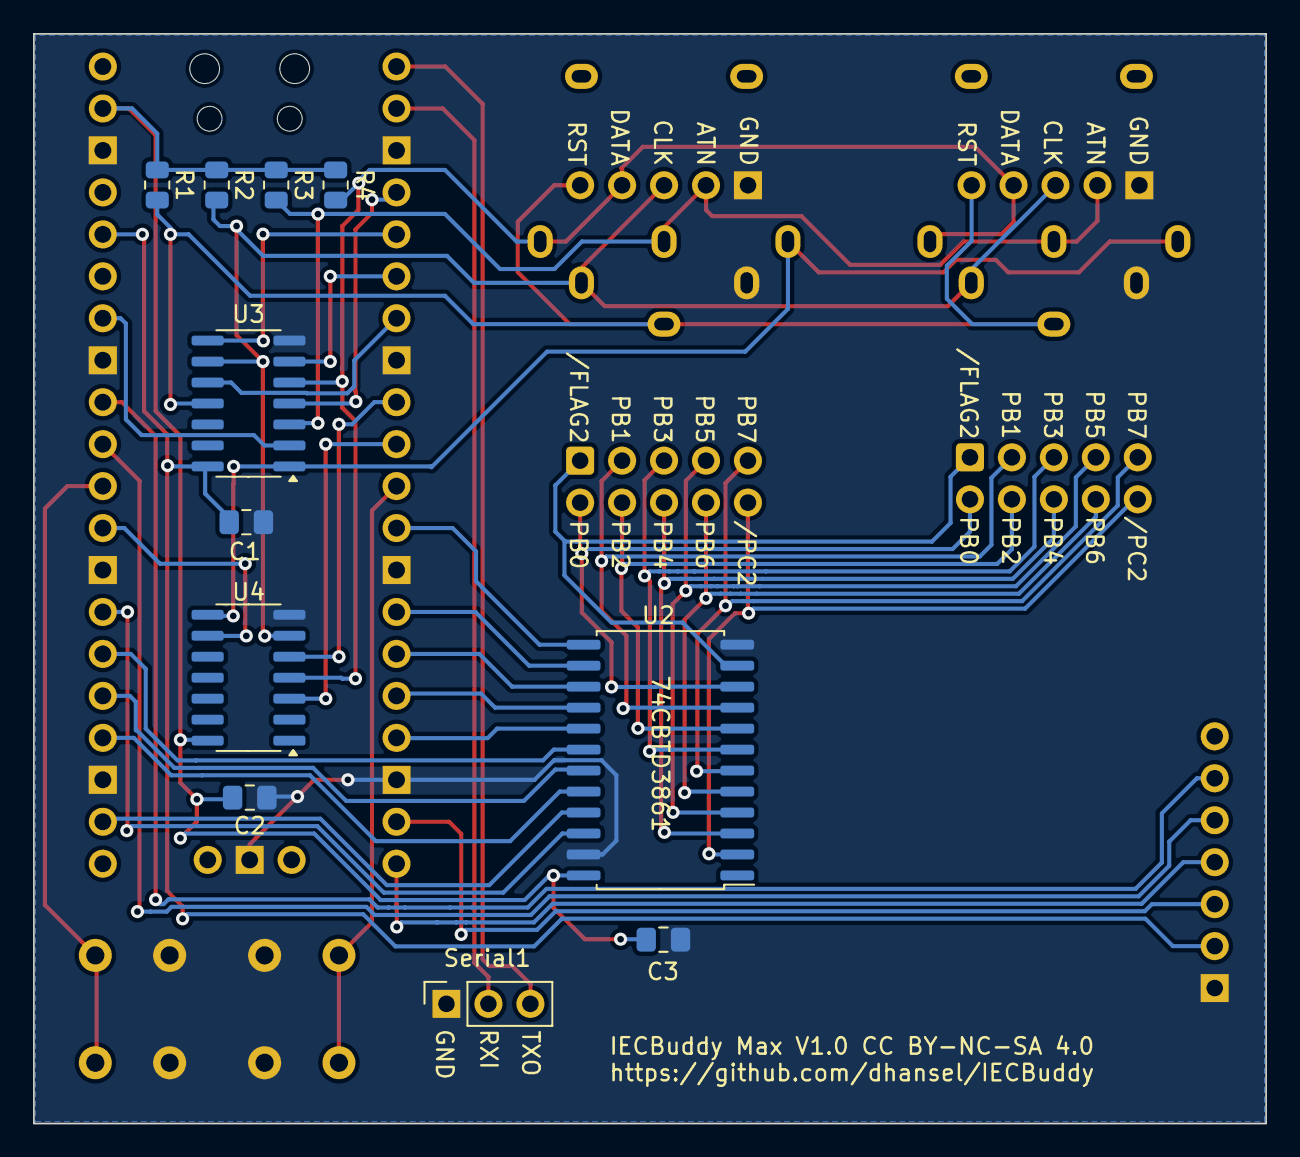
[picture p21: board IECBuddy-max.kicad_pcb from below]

Board: 2 copper layers, 74.6 x 66.0 mm, 21 parts (11 on the bottom side), 44 nets.

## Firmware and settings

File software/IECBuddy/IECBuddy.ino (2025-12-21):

// -----------------------------------------------------------------------------
// Copyright (C) 2025 David Hansel
//
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
// You should have receikved a copy of the GNU General Public License
// along with this program; if not, write to the Free Software Foundation,
// Inc., 51 Franklin Street, Fifth Floor, Boston, MA 02110-1301  USA
// -----------------------------------------------------------------------------

#include "SKDrive.h"
#include "SKPrinter.h"
#include "SKDisplay.h"
#include "SKConfig.h"
#include "Pins.h"
#include "src/IECDevice/IECBusHandler.h"
#include "protocol.h"
#include <algorithm>
using namespace std;

#define DEBUG 0

/*
--- to debug LittleFS, add the following to the top of
  C:/Users/[..]/AppData/Local/Arduino15/packages/rp2040/hardware/rp2040/[version]/libraries/LittleFS/lib/littlefs/lfs_util.h
  #define LFS_YES_TRACE
  #undef LFS_NO_DEBUG
  #undef LFS_NO_WARN
  #undef LFS_NO_ERROR
*/


#if DEBUG>0
extern "C" int printf(const char* format, ... )
{
  int res = 0;

  char buffer[512];
  va_list args;

  va_start(args, format);
  res = vsnprintf(buffer, 512, format, args);
  va_end(args);
  
  for(int i=0; i<512 && buffer[i]; i++)
    { 
      if( buffer[i]=='\n' ) Serial1.write('\r');
      Serial1.write(buffer[i]);
    }

  return res;
}

#include <malloc.h>

static uint32_t getTotalHeap()
{
   extern char __StackLimit, __bss_end__;
   return &__StackLimit  - &__bss_end__;
}

static uint32_t getFreeHeap()
{
  struct mallinfo m = mallinfo();
  return getTotalHeap() - m.uordblks;
}

#endif


// IEC bus device number
#define DEVICE_NUMBER  8

SKConfig   skConfig;
SKDrive    skDrive(DEVICE_NUMBER, PIN_DRIVE_LED);
SKPrinter  skPrinter(4, PRINTDATAFILE);
SKDisplay *skDisplay = NULL;

// if RESET pin is not defined, set it to 0xFF (not assigned)
#ifndef PIN_IEC_RESET
#define PIN_IEC_RESET 0xFF
#endif

#ifdef IEC_USE_LINE_DRIVERS
IECBusHandler iecBus(PIN_IEC_ATN, PIN_IEC_CLK, PIN_IEC_CLK_OUT, PIN_IEC_DATA, PIN_IEC_DATA_OUT, PIN_IEC_RESET);
#else
IECBusHandler iecBus(PIN_IEC_ATN, PIN_IEC_CLK, PIN_IEC_DATA, PIN_IEC_RESET);
#endif


// the "mytime" function is used to implement tracking of whether a file was
// modified by the C64. Whenever a file that was opened for writing is closed,
// LittleFS updates its modification time with the result returned by the
// function set via LittleFS.setTimeCallback(). After opening a file via our
// SK64 communication we make sure that s_modTime!=0 before closing it, 
// therefore resetting it to good (NOT modified). Otherwise we make sure that
// s_modTime==0 (i.e. dirty, modified). 
// We use "1" for "not modified" because if files are uploaded via the Arduino
// "LittleFS data upload" function they get a non-zero modification date.
static time_t s_modTime = 0;
time_t mytime()
{
  //Serial1.printf("mytime:%i\r\n", s_modTime);
  return s_modTime;
}


bool send_data(uint32_t length, const uint8_t *buffer)
{
  uint32_t n = Serial.write(buffer, length);

#if DEBUG>=2
  if( n!=length )
    Serial1.printf("=> ERROR (%i/%i): ", n, length);
  else
    Serial1.printf("=> %i: ", length);

  for(uint32_t i=0; i<length; i++) 
    {
      if( DEBUG==2 && i==10 ) { Serial1.printf("[...]"); break; }
      Serial1.printf("%02X ", buffer[i]);
    }

  Serial1.printf("\r\n");
#elif DEBUG>0
  if( n!=length )
    Serial1.printf("SEND ERROR (%i of %i sent)\r\n", n, length);
#endif

  return n==length;
}


bool recv_data(uint32_t length, uint8_t *buffer)
{
  uint32_t n = Serial.readBytes(buffer, length);

#if DEBUG>=2
  if( n!=length )
    Serial1.printf("<= ERROR (%i/%i)", n, length);
  else
    Serial1.printf("<= %i: ", length);

  for(uint32_t i=0; i<n; i++) 
    {
      if( DEBUG==2 && i==10 ) { Serial1.printf("[...]"); break; }
      Serial1.printf("%02X ", buffer[i]);
    }
  Serial1.printf("\r\n");
#elif DEBUG>0
  if( n!=length )
    Serial1.printf("RECEIVE ERROR (%i of %i received)\r\n", n, length);
#endif
  
  return n==length;
}


void sendDriveStatus()
{
#if DEBUG>0
  Serial1.printf("sendDriveStatus()\r\n");
#endif

  char buffer[255];
  skDrive.getStatus(buffer, 255);
  send_string(buffer);
}


void execDriveCommand()
{
#if DEBUG>0
  Serial1.printf("execDriveCommand()\r\n");
#endif

  string cmd;
  if( recv_string(cmd) )
    {
#if DEBUG>0
      Serial1.printf("command: %s\r\n", cmd.c_str());
#endif
      if( skDrive.getMountedImageName()==NULL )
        skDrive.execute(cmd.c_str());
      else
        {
          // execute command on SD card (not in currently mounted image)
          string imageName(skDrive.getMountedImageName());
          skDrive.unmountDiskImage();
          skDrive.execute(cmd.c_str());
          skDrive.mountDiskImage(imageName.c_str());
        }

      send_status(ST_OK);
    }
}


void rmDirRecursive(string dirName)
{
  Dir dir = LittleFS.openDir(dirName.c_str());
  while( dir.next() )
    {
      string fullName = dirName+string("/")+string(dir.fileName().c_str());
#if DEBUG>0
      Serial1.printf("remove: %s\r\n", fullName.c_str());
#endif
      if( dir.isDirectory() )
        {
          rmDirRecursive(fullName);
          LittleFS.rmdir(fullName.c_str());
        }
      else
        LittleFS.remove(fullName.c_str());
    }
}


void sendDir()
{
  string s = "/";

#if DEBUG>0
  Serial1.printf("sendDir()\r\n");
#endif

  // check whether directory exists
  File f = LittleFS.open(s.c_str(), "r");
  bool ok = f && f.isDirectory();
  f.close();
  
  // send status code
  ok = send_status(ok ? ST_OK : ST_INVALID_DIR);

  if( ok )
    {
      // send available space
      struct FSInfo info;
      LittleFS.info(info);
      ok = send_uint(info.totalBytes-info.usedBytes);
    }

  if( ok )
    {
      // send directory
      Dir dir = LittleFS.openDir(s.c_str());
      while( dir.next() && ok )
        {
#if DEBUG>0
          Serial1.printf("%s %i %u\r\n", dir.fileName().c_str(), dir.fileSize(), dir.fileTime());
#endif
          uint32_t flags = 0;

          // we set the files' lastWrite() time to "0" whenever the file 
          // is modified and set it back to "1" when a file is retrieved
          // or originally uploaded
          if( dir.fileTime()==0 ) flags |= FF_MODIFIED;

          // send flags, file size and file name
          if( ok ) ok = send_uint(flags);
          if( ok ) ok = send_sint(dir.fileSize());
          if( ok ) ok = send_string(dir.fileName().c_str());
        }
      
      // send end-of-dir marker
      if( ok ) send_uint(0xFFFFFFFF);
    }
}


void sendFile()
{
  string fileName;

#if DEBUG>0
  Serial1.printf("sendFile()\r\n");
#endif
  
  // receive file name
  if( recv_string(fileName) )
    {
      // convert "/" and "\" to "-" (we don't support subdirectories)
      transform(fileName.begin(), fileName.end(), fileName.begin(), [](unsigned char c){ return c=='/' || c=='\\' ? '-' : c; });

#if DEBUG>0
      Serial1.printf("name=%s\r\n", fileName.c_str());
#endif

      File file = LittleFS.open(fileName.c_str(), "r+");
      if( file )
        {
          StatusType status = ST_OK;
          uint32_t length = file.size();
#if DEBUG>0
          Serial1.printf("length=%u\r\n", length);
#endif
          // send file length
          if( status==ST_OK )
            if( !send_uint(length) )
              status = ST_COM_ERROR;

          // send status
          if( !send_status(ST_OK) ) status = ST_COM_ERROR;

          skDisplay->showTransmitMessage("Sending", fileName);
          skDisplay->startProgress(length);

          // send data
          uint8_t buf[1024];
          while( status==ST_OK && length>0 )
            {
              uint32_t n = min(1024u, length);
              uint32_t i = file.read(buf, n);
#if DEBUG==1
              Serial1.write('.');
#endif
              // receiver expects a full block so we send it even if read failed
              if( !send_data(n, buf) ) status = ST_COM_ERROR;
              
              // compute and send checksum for data block
              uint8_t checksum = 0;
              for(uint32_t j=0; j<i; j++) checksum ^= buf[j];
              if( status==ST_OK )
                if( !send_data(1, &checksum) )
                  status = ST_COM_ERROR;
              
              // check if we successfully read the data
              if( i!=n ) status = ST_READ_ERROR;
              
              // send status
              if( status!=ST_COM_ERROR )
                if( !send_status(status) )
                  status = ST_COM_ERROR;
              
              // receive status
              if( status==ST_OK )
                status = recv_status();
              
              skDisplay->updateProgress(i);
              length -= i;
            }

          // close file (see comment in mytime() function above)
          s_modTime = 1;
          file.close();
          s_modTime = 0;

          skDisplay->redraw();
        }
      else
        {
          // receiver expects a length => send 0
          send_uint(0);
          // send error
          send_status(ST_INVALID_FILE);
        }
    }

#if DEBUG==1
  Serial1.println();
#endif
}


void receiveFile()
{
  string fileName;

#if DEBUG>0
  Serial1.printf("receiveFile()");
#endif

  // receive file name
  if( recv_string(fileName) )
    {
      StatusType status = ST_OK;

      // convert "/" and "\" to "-" (we don't support subdirectories)
      transform(fileName.begin(), fileName.end(), fileName.begin(), [](unsigned char c){ return c=='/' || c=='\\' ? '-' : c; });

      // receive length
      uint32_t length;
      if( status==ST_OK )
        if( !recv_uint(length) )
          status = ST_COM_ERROR;

      if( status==ST_OK )
        {
          // make sure that either the file name has a .XYZ extension or it is of form "$...$" (hidden file)
          int len = fileName.length();
          if( len<4 || fileName[len-4]!='.' || !isalphanum(fileName[len-3]) || !isalphanum(fileName[len-2]) || !isalphanum(fileName[len-1]) )
            if( len<2 || fileName[0]!='$' || fileName[len-1]!='$' )
              status = ST_INVALID_FILE;
        }

      if( status==ST_OK )
        {
          // check whether a file with this name already exists
          if( LittleFS.exists(fileName.c_str()) )
            status = ST_FILE_EXISTS;
        }

      if( status==ST_OK )
        {
          // check available space
          // according to https://github.com/littlefs-project/littlefs/issues/533
          // LittleFS requires ~6 blocks of free storage space to work with
          struct FSInfo info;
          LittleFS.info(info);
          if( length > info.totalBytes-info.usedBytes-6*info.blockSize )
            status = ST_DRIVE_FULL;
        }

#if DEBUG>0
      Serial1.printf(" name=%s, length=%u ", fileName.c_str(), length);
#endif

      // open file
      if( status==ST_OK )
        {
          File file = LittleFS.open(fileName.c_str(), "w");
          if( file )
            {
              // send initial status
              if( !send_status(ST_OK) ) status = ST_COM_ERROR;

              skDisplay->showTransmitMessage("Receiving", fileName);
              skDisplay->startProgress(length);

              // receive data
              uint8_t buf[1024];
              while( status==ST_OK && length>0 )
                {
                  uint8_t checksum1, checksum2;
                  uint32_t n = min(1024u, length);
#if DEBUG>0
                  Serial1.write('.');
#endif
                  // receive data block
                  if( !recv_data(n, buf) )
                    status = ST_COM_ERROR;
          
                  // compute and receive checksum
                  if( status==ST_OK )
                    {
                      uint8_t checksum1=0, checksum2=0;
                      for(uint32_t j=0; j<n; j++) checksum1 ^= buf[j];

                      if( !recv_data(1, &checksum2) )
                        status = ST_COM_ERROR;
                      else if( checksum1!=checksum2 )
                        status = ST_CHECKSUM_ERROR;
                    }

                  // receive transmitter status
                  if( status!=ST_COM_ERROR && recv_status()==ST_OK )
                    {
                      // save data block
                      if( status==ST_OK )
                        if( file.write(buf, n) != n )
                          status = ST_WRITE_ERROR;

                      // send our status
                      if( !send_status(status) )
                        status = ST_COM_ERROR;
                    }
                  
                  skDisplay->updateProgress(n);
                  length -= n;
                }
              
              // close file (see comment in mytime() function above)
              s_modTime = 1;
              file.close();
              s_modTime = 0;

              // if there was a transmission error then remove 
              // received (incomplete) file
              if( status!=ST_OK )
                LittleFS.remove(fileName.c_str());

              skDisplay->redraw();
            }
          else
            send_status(ST_WRITE_ERROR);
        }
      else
        send_status(status);
    }

#if DEBUG>0
  Serial1.println();
#endif
}


void deleteFile()
{
  string fileName;

  // receive file name
  if( recv_string(fileName) )
    {
      StatusType status = ST_OK;

      if( !LittleFS.exists(fileName.c_str()) )
        status = ST_FILE_NOT_FOUND;
      else if( !LittleFS.remove(fileName.c_str()) )
        status = ST_WRITE_ERROR;

      send_status(status);
    }
}


void mountDiskImage()
{
  string fileName;

  // receive image name
  if( recv_string(fileName) )
    {
      StatusType status = ST_OK;

      // check whether a file with this name exists
      if( LittleFS.exists(fileName.c_str()) )
        status = skDrive.mountDiskImage(fileName.c_str()) ? ST_OK : ST_INVALID_FILE;
      else
        status = ST_FILE_NOT_FOUND;
      
      send_status(status);
    }
}


void unmountDiskImage()
{
  skDrive.unmountDiskImage();
  send_status(ST_OK);
}


void getMountedDiskImage()
{
  const char *filename = skDrive.getMountedImageName();
  send_string(filename ? filename : "");
}



void setConfigValue()
{
#if DEBUG>0
  Serial1.printf("setConfigValue()\r\n");
#endif
  string key, value;
  if( recv_string(key) && recv_string(value) )
    {
#if DEBUG>0
      Serial1.printf("%s => %s\r\n", key.c_str(), value.c_str());
#endif
      skConfig.setValue(key, value);
      if( key=="rotate" )
        {
          skDisplay->setRotation(atoi(value.c_str()));
          const char *image = skDrive.getMountedImageName();
          skDisplay->setCurrentImageName(image ? string(image) : "");
        }
      send_status(ST_OK);
    }
}


void getConfigValue()
{
#if DEBUG>0
  Serial1.printf("getConfigValue()\r\n");
#endif
  string key;
  if( recv_string(key) )
    {
      string value = skConfig.getValue(key);
#if DEBUG>0
      Serial1.printf("%s => %s\r\n", key.c_str(), value.c_str());
#endif
      send_string(value);
    }
}


void clearConfig()
{
  skConfig.clear();
  send_status(ST_OK);
}


void reboot()
{
  send_status(ST_OK);
  Serial.flush();
  delay(100);
  rp2040.reboot();
}


void showBitmap()
{
  StatusType status = ST_OK;

  int32_t  x, y;
  uint32_t w, h;
  if( !recv_sint(x) || !recv_sint(y) || !recv_uint(w) || !recv_uint(h) )
    status = ST_COM_ERROR;

  if( status==ST_OK )
    {
      // startImage() returns number of bytes per pixel
      uint32_t bpp    = skDisplay->startImage(x, y, w, h);
      uint32_t nbytes = w*h*bpp;
      uint8_t  buffer[1024];

      if( bpp==0 )
        status = ST_DRIVE_FULL;

      while( nbytes>0 && status==ST_OK )
        {
          uint32_t n = min(1024, nbytes);
          if( send_status(ST_OK) )
            {
              if( recv_data(n, buffer) )
                skDisplay->addImageData(buffer, n);
              else
                status = ST_COM_ERROR;
            }
          else
            status = ST_COM_ERROR;

          nbytes -= n;
        }

      skDisplay->endImage();
      skDisplay->redraw();
    }
  
  send_status(status);
}


void showGIF()
{
  StatusType status = ST_OK;

  int32_t  x, y;
  uint32_t size;
  if( !recv_sint(x) || !recv_sint(y) || !recv_uint(size) )
    status = ST_COM_ERROR;
  
  if( status==ST_OK )
    {
      uint8_t *buffer = (uint8_t *) malloc(size);
      if( buffer )
        {
          uint32_t nbytes = size;
          uint8_t *ptr = buffer;
          while( nbytes>0 && status==ST_OK )
            {
              uint32_t n = min(1024, nbytes);
              if( !send_status(ST_OK) || !recv_data(n, ptr) )
                status = ST_COM_ERROR;
              
              nbytes -= n;
              ptr    += n;
            }
          
          if( status==ST_OK )
            skDisplay->setBackgroundImageGIF(buffer, size, x, y);

          free(buffer);
        }
      else
        status = ST_DRIVE_FULL;
    }
  
  send_status(status);
}


void execCmd(CommandType cmd)
{
  switch( cmd )
    {
    case CMD_DIR:            sendDir();  break;
    case CMD_GETFILE:        sendFile(); break;
    case CMD_PUTFILE:        receiveFile(); break;
    case CMD_DRIVESTATUS:    sendDriveStatus(); break;
    case CMD_DRIVECMD:       execDriveCommand(); break;
    case CMD_MOUNT:          mountDiskImage(); break;
    case CMD_UNMOUNT:        unmountDiskImage(); break;
    case CMD_GET_MOUNTED:    getMountedDiskImage(); break;
    case CMD_SET_CONFIG_VAL: setConfigValue(); break;
    case CMD_GET_CONFIG_VAL: getConfigValue(); break;
    case CMD_CLEAR_CONFIG:   clearConfig(); break;
    case CMD_DELETE_FILE:    deleteFile(); break;
    case CMD_SHOW_BITMAP:    showBitmap(); break;
    case CMD_SHOW_GIF:       showGIF(); break;
    case CMD_REBOOT:         reboot(); break;

    default: 
      {
#if DEBUG>0
        Serial1.printf("INVALID COMMAND: %02X\r\n", cmd);
#endif
        send_status(ST_INVALID_COMMAND);
        break;
      }
    }
}


void setup()
{
  Serial.begin(115200);

#if DEBUG>0
  Serial1.begin(115200);
  Serial1.print("DEBUG START\r\n");
#endif

  LittleFS.begin();
  LittleFS.setTimeCallback(mytime);

  skConfig.begin("/$CONFIG$");

  // setting fsformat==1 will format filesystem on reboot
  if( skConfig.getValue("fsformat")=="1" )
    {
      LittleFS.format();
      skConfig.clear();
    }

  string displayType = skConfig.getValue("display");
  if( displayType.empty() )
    {
#if defined(SUPPORT_ST7789)
      displayType = "ST7789";
#else
      displayType = "NONE";
#endif
      skConfig.setValue("display", displayType);
    }

#if DEBUG>0
  Serial1.printf("Display type: %s\r\n", displayType.c_str());
#endif
  skDisplay = SKDisplay::Create(displayType);

  skDisplay->begin(atoi(skConfig.getValue("rotate").c_str()));

  skDrive.setConfig(&skConfig);
  skDrive.setDisplay(skDisplay);
  skPrinter.setConfig(&skConfig);
  skPrinter.setDisplay(skDisplay);

#ifdef IEC_SUPPORT_PARALLEL
  iecBus.setParallelPins(PIN_PAR_FLAG2, PIN_PAR_PC2,
                         PIN_PAR_PB0, PIN_PAR_PB1, PIN_PAR_PB2, PIN_PAR_PB3,
                         PIN_PAR_PB4, PIN_PAR_PB5, PIN_PAR_PB6, PIN_PAR_PB7);
#endif

  iecBus.attachDevice(&skDrive);
  iecBus.attachDevice(&skPrinter);
  iecBus.begin();
}


void loop()
{
  iecBus.task();

  if( Serial.available()>0 )
    {
#if DEBUG>1
      Serial1.print("command receive...\r\n");
      CommandType cmd = recv_command();
      Serial1.printf("command execute %02X... (free heap=%i)\r\n", cmd, getFreeHeap());
      if( cmd != CMD_INVALID ) execCmd(cmd);
      Serial1.printf("command done (free heap=%i)\r\n", getFreeHeap());
#else
      CommandType cmd = recv_command();
      if( cmd != CMD_INVALID ) execCmd(cmd);
#endif
    }
}

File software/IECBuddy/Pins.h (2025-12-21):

#ifndef PINS_H
#define PINS_H

// GPIO 0/1 are UART TX/RX, reserved for debugging
// On Pi Pico,    GPIO 16+22+28 are currently not used (GPIO 23-25,29 not available on board)
// On RP2040-One, GPIO 9-13,28+29 are currently not used (GPIO 16-25 not available on board)

// The ATN/CLK/DATA IEC connections are the only required pins
// (RESET can be commented out if not connected)
#define PIN_IEC_ATN           2
#define PIN_IEC_CLK           3
#define PIN_IEC_DATA          4
#define PIN_IEC_RESET         5

// Un-comment both of these if using 74LS06 line driver for CLK/DATA line output
//#define PIN_IEC_CLK_OUT       6
//#define PIN_IEC_DATA_OUT      7

// "Disk Change" button
#define PIN_BUTTON            8

// Parallel cable (for DolphinDos) is only supported on Pi Pico boards (more pins)
// (commenting out these #defines will remove DolphinDos support on the Pico too)
#if defined(ARDUINO_RASPBERRY_PI_PICO) || defined(ARDUINO_RASPBERRY_PI_PICO_2)
#define PIN_PAR_FLAG2         9
#define PIN_PAR_PB0          10
#define PIN_PAR_PB1          11
#define PIN_PAR_PB2          12
#define PIN_PAR_PB3          13
#define PIN_PAR_PB4          17
#define PIN_PAR_PB5          18
#define PIN_PAR_PB6          19
#define PIN_PAR_PB7          20
#define PIN_PAR_PC2          21
#endif

// Waveshare RP2040-One board uses an RGB LED on GPIO16
#if defined(ARDUINO_WAVESHARE_RP2040_ONE) || defined(ARDUINO_GENERIC_RP2350)
#define PIN_DRIVE_LED_IS_NEOPIXEL_RGB
#define PIN_DRIVE_LED        16
#elif defined(PIN_LED)
#define PIN_DRIVE_LED        PIN_LED
#endif

// Un-comment PIN_ST7789* to support a ST7789 TFT IPS display
// If enabled, the "GFX Library for Arduino" library must be installed in the Arduino IDE 
// GPIO 0-7 use SPI0
// GPIO8-16 use SPI1
//#define PIN_ST7789_SPI       SPI1
//#define PIN_ST7789_SPI_SCL   14
//#define PIN_ST7789_SPI_COPI  15
//#define PIN_ST7789_RES       26
//#define PIN_ST7789_DC        27

#endif

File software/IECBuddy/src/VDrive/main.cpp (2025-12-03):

#if !defined(ARDUINO) && defined(__GNUC__)

#include <stdio.h>
#include <string.h>
#include <cstdlib>

#include "VDriveClass.h"


int main_(VDrive *drive, int argc, char **argv)
{
  printf("CMD: ");
  for(int i=2; i<argc; i++) printf("%s ", argv[i]);
  printf("\n");

  if( argc>1 )
    {
      if( argc>2 && (strcmp(argv[2], "list")==0 || strcmp(argv[2], "dir")==0) )
        drive->printDir();
      else if( argc>2 && strcmp(argv[2], "create")==0 )
        {
          char name[17];
          if( argc>3 )
            strncpy(name, argv[3], 16);
          else
            {
              char *dot = strchr(argv[1], '.');
              if( dot!=NULL ) strncpy(name, argv[1], (dot-argv[1])<16 ? (dot-argv[1]) : 16);
              name[16] = 0;
            }

          if( VDrive::createDiskImage(argv[1], NULL, name, true) )
            printf("Image %s created", argv[1]);
        }
      else if( argc>3 && strcmp(argv[2], "read")==0 )
        {
          for(int i=3; i<argc; i++)
            {
              //const char *testfile = "\xa0\x20\x20\x20\xa0\x20\xa0\x20";
              const char *testfile = "\x00";

              int channel = 2;
              printf("Reading file '%s' ...\n", argv[i]);
              bool ok;
              if( strcmp(argv[i], "test")==0 )
                ok = drive->openFile(channel, testfile, 1, false);
              else
                ok = drive->openFile(channel, argv[i], -1, true);

              if( ok )
                {
                  FILE *outfile = fopen(argv[i][0]==':' ? argv[i]+1 : argv[i], "wb");
                  if( outfile )
                    {
                      bool eof = false;
                      uint8_t buf[128];
                      while( drive->isFileOk(channel) && !eof )
                        {
                          size_t n = 128;
                          if( drive->read(channel, buf, &n, &eof) )
                            {
                              fwrite(buf, 1, n, outfile);
                            }
                          else
                            {
                              printf("Error (read): %s\n", drive->getStatusString());
                              break;
                            }
                        }

                      fclose(outfile);
                    }
                  else
                    printf("Can not write to local file: %s\n", argv[i]);

                  drive->closeFile(channel);
                }
              else
                printf("Error (open): %s\n", drive->getStatusString());
            }
        }
      else if( argc>3 && strcmp(argv[2], "write")==0 )
        {
          FILE *infile = fopen(argv[3], "rb");
          if( infile )
            {
              if( drive->openFile(1, argv[3], true) )
                {
                  uint8_t buf[128];
                  while( drive->isFileOk(1) && !feof(infile) )
                    {
                      size_t n = fread(buf, 1, 128, infile);
                      if( !drive->write(1, buf, &n) )
                        {
                          printf("Error (write): %s\n", drive->getStatusString());
                          break;
                        }
                    }
          
                  drive->closeFile(1);
                }
              else
                printf("Error (open): %s\n", drive->getStatusString());

              fclose(infile);
            }
          else
            printf("Can not read from local file: %s\n", argv[3]);
        }
      else if( argc>4 && strcmp(argv[2], "bread")==0 )
        {
          int channel = 2;
          char cmd[100];
          snprintf(cmd, 100, "U1 %i 0,%s,%s", channel, argv[3], argv[4]);
          if( drive->openFile(channel, "#") && (drive->execute(cmd, strlen(cmd)) || true) )
            {
              size_t n = 1;
              uint8_t b;
              bool eoi;
              for(int i=0; i<256; i++)
                {
                  if( !drive->read(channel, &b, &n, &eoi) )
                    printf("XX ");
                  else if( n==0 )
                    printf("-- ");
                  else
                    printf("%02X ", b);

                  if( (i%16)==15 ) printf("\n");
                }

              drive->closeFile(channel);
            }

          printf("Status: %s\n", drive->getStatusString());
        }
      else if( argc>4 && strcmp(argv[2], "bmread")==0 )
        {
          char buf[100];
          snprintf(buf, 100, "U1 8 0,%s,%s", argv[3], argv[4]);
          if( drive->openFile(8, "#2") && drive->execute(buf, strlen(buf)) && drive->execute("M-R\x00\x05\0x00", 6) )
            {
              bool eoi = false;
              while( !eoi )
                {
                  size_t len = drive->getStatusBuffer(buf, 40, &eoi);
                  for(int j=0; j<len; j++) printf("%02X ", (unsigned char) buf[j]);
                  printf("\n");
                }
              drive->closeFile(8);
            }

          printf("Status: %s\n", drive->getStatusString());
        }
      else if( argc>4 && strcmp(argv[2], "rread")==0 )
        {
          int channel = 2;
          if( drive->openFile(channel, argv[3], true) )
            {
              uint8_t buf[256];
              buf[0] = 'P';
              buf[1] = 96 + channel;
              buf[2] = atoi(argv[4]);
              buf[3] = 0;
              buf[4] = 1;
              if( drive->execute((const char *) buf, 5) )
                {
                  int n = argc>5 ? atoi(argv[5]) : 1;
                  for(int j=0; j<n; j++)
                    {
                      bool eoi = false;
                      while( !eoi )
                        {
                          size_t n = 1;
                          if( !drive->read(channel, buf, &n, &eoi) )
                            { printf("READ-ERROR\n"); break; }
                              
                          for(size_t i=0; i<n; i++) printf("%02X ", buf[i]);
                        }
                      printf("\n");
                    }
                }

              printf("Status: %s\n", drive->getStatusString());

              drive->closeFile(channel);
            }
        }
      else if( argc>5 && strcmp(argv[2], "bwrite")==0 )
        {
          if( drive->openFile(2, "#") )
            {
              size_t n = 256;
              uint8_t buf[256];
              memset(buf, atoi(argv[5]), 256);
              if( drive->write(2, buf, &n) && n==256 ) 
                {
                  char cmd[100];
                  snprintf(cmd, 100, "U2 2 0,%s,%s", argv[3], argv[4]);
                  drive->execute(cmd, strlen(cmd));
                }

              drive->closeFile(2);
            }
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

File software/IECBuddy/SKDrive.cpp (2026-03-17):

// -----------------------------------------------------------------------------
// Copyright (C) 2025 David Hansel
//
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
// You should have receikved a copy of the GNU General Public License
// along with this program; if not, write to the Free Software Foundation,
// Inc., 51 Franklin Street, Fifth Floor, Boston, MA 02110-1301  USA
// -----------------------------------------------------------------------------

#include "SKDrive.h"
#include "SKConfig.h"
#include "SKDisplay.h"
#include "Pins.h"
#include <LittleFS.h>
#include <algorithm>

using namespace std;

#define E_OK          0
#define E_SCRATCHED   1
#define E_READ       20
#define E_WRITEPROT  26
#define E_WRITE      28
#define E_INVCMD     31
#define E_INVNAME    33
#define E_NOTFOUND   62
#define E_EXISTS     63
#define E_MISMATCH   64
#define E_SPLASH     73
#define E_NOTREADY   74
#define E_MEMEXE     97
#define E_TOOMANY    98
#define E_VDRIVE     99

#define FT_NONE      0x00
#define FT_PRG       0x01
#define FT_SEQ       0x02
#define FT_ANY       0xFF

#ifndef min
#define min(a,b) ((a)<(b) ? (a) : (b))
#endif

#ifdef PIN_DRIVE_LED_IS_NEOPIXEL_RGB
#include <Adafruit_NeoPixel.h>
static Adafruit_NeoPixel s_led(1, 16, NEO_RGB + NEO_KHZ800);
#define BRIGHTNESS 25
#endif

#define LED_OFF   0
#define LED_RED   1
#define LED_GREEN 2
#define LED_BLUE  3

// ----------------------------------------------------------------------------------------------

static string tolower(string s)
{
  transform(s.begin(), s.end(), s.begin(), [](unsigned char c){ return std::tolower(c); });
  return s;
}

static bool endsWith(const std::string &str, const std::string &suffix)
{
    return str.size() >= suffix.size() &&
           str.compare(str.size() - suffix.size(), suffix.size(), suffix) == 0;
}


static bool changeDisk = false;
static void diskChangeButtonFcn()
{
  static unsigned long debounceTime = 0;
  static bool debounceState = true;

  bool state = digitalRead(PIN_BUTTON);
  if( state!=debounceState && millis()>debounceTime )
    {
      debounceState = state;
      debounceTime  = millis()+20;
      if( !state ) changeDisk = true;
    }
}


SKDrive::SKDrive(uint8_t devnum, uint8_t pinLED) :
  IECFileDevice(devnum)
{
  m_pinLED = pinLED;
  m_dirOpen = false;
  m_drive = NULL;
  m_curFileChannel = -1;
  m_display = NULL;
  m_lastActivity = 0;
  m_showExt = false;
}


void SKDrive::begin()
{
  pinMode(PIN_BUTTON, INPUT_PULLUP);
  attachInterrupt(PIN_BUTTON, diskChangeButtonFcn, CHANGE);

  unsigned long ledTestEnd = millis() + 500;

  if( m_pinLED<0xFF ) 
    {
#ifdef PIN_DRIVE_LED_IS_NEOPIXEL_RGB
      s_led.setPin(m_pinLED); 
      s_led.begin();
#else
      pinMode(m_pinLED, OUTPUT); 
#endif
    }

  setLEDState(LED_GREEN);
  m_errorCode = E_SPLASH;
  m_drive = new VDrive(0);

  // read configuration settings
  int d = std::atoi(m_config->getValue("device").c_str());
  if( d>=8 && d<=15 && d!=m_devnr ) setDeviceNumber(d);
  string s = m_config->getValue("diskflush");
  m_diskFlushTimeout = s.empty() ? 500 : std::atoi(s.c_str());
  m_showExt = std::atoi(m_config->getValue("showext").c_str())!=0;

  m_display->redraw();
  updateDisplayStatus();

  // call this after m_display->begin() since this sets all IEC and parallel cable
  // pins to GPIO mode, ensuring that any pins that were previously set as I2C/SPI
  // (because of defaults) get set to GPIO mode.
  IECFileDevice::begin();

  if( m_pinLED<0xFF ) 
    {
      unsigned long t = millis();
      if( t<ledTestEnd ) delay(ledTestEnd-t);
      setLEDState(LED_OFF);
    }
}
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

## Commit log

2025-03-27 Added configuration file and capability to change device number
2025-04-01 - added serial commands to mount/unmount a disk image and query currently mounted image - fixed issue where mounting an image within a ZIP file did not work - fixed issue where "N:name.d64" on top le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
2025-04-04 support using 74LS06/74LS07 line drivers for CLK/DATA lines
2025-04-04 Fixed rare time issue with PiPico when saving under Dolphin Dos and writing data to flash with LittleFS. Also fixed some issues with line driver support
2025-04-14 Moved debug pin for PiPico to GPIO28
2025-04-14 Added support for SSD1306 OLED display (SDA=GPIO20, SCL=GPIO21) and button for switching disk images (GPIO22).
2025-04-24 Initial support for ST7789 display (currently disabled)
2025-04-24 Print drive status after executing command
2025-04-24 Be more lenient about "CD" syntax: - ignore any characters between "CD" and first ":" (if one exists) - to exit from mounted image: CD.. CD/ CD< [left arrow] CD^ [up arrow]
2025-04-26 Various improvements: - any file with naming schema $*$ is invisible on IEC bus but accessible over serial protocol - added SET_CONFIG_VAL and GET_CONFIG_VAL commands to serial protocol - added DOS c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
2025-04-27 Fixed some issues with hidden files. Support (wildcard) patterns when loading directory.
    [IECSidekick64.cpp]
2025-04-27 Removed Chip Select pin defition (not used, not needed)
2025-04-29 Keep protocol code in RAM (instead of flash) to prevent timing issues on some PiPico boards with (larger/slower) flash memory.
2025-05-02 Fixed (recently introduced) issue with pattern matching when loading
    [IECSidekick64.cpp]
2025-05-03 Allow wildcards in "CD" command. Produce better error message when CD fails but file exists (attempting to CD into a regular file).
    [IECSidekick64.cpp]
2025-05-07 Allow CD from within one disk image into another if the path is prefixed by "/", i.e. if a disk image is currently mounted, "CD:OTHERIMAGE.D64" still does NOT work (because a disk image cannot be con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
    [IECSidekick64.cpp]
2025-05-10 Added setup for line drivers (74LS07), enable "#define USE_LINE_DRIVERS" in src/IECDevice/IECConfig.h to use.
2025-05-17 Rearranged pin assignments so they work for PiPico and Waveshare RP2040-One boards. Consolidated all pin definitions into Pins.h header file
2025-05-18 Changed handling of file extensions. - Files received via USB _must_ have a 3-character extension (.XYZ), otherwise the receive operation fails - Files generated via IEC always get either a .PRG or .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
    [IECSidekick64.cpp]
2025-05-19 Fixed issues with file extensions of file names longer than 16 characters
    [IECSidekick64.cpp]
2025-05-19 Remove extension from file name for DIR (got broken in previous commit)
    [IECSidekick64.cpp]
2025-05-20 If a "favlist" is defined in the config then pressing the DiskChange button now rotates through disk images defined in there.
2025-06-20 Support SpeedDos protocol and clean up parallel cable code
2025-07-14 Added printer support
2025-07-19 Added missing (new) files
    [IECPrinter.cpp]
2025-07-28 Fixed error when opening file if given file name starts with ":" (":" must be ignored in that case).
2025-08-19 Do not produce a NO_CHANNEL when opening a file on a channel that is already open. Commodore drives just re-open the channel with the new file in that case. This caused errors when loading Mars Saga 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
2025-08-24 Brought up-to-date with recent IECDevice library changes (fixed some timing issues with FC3 and AR6 protocols)
    [IECFileDevice.cpp]
2025-08-29 Added possibility to specify background image: sk64test bitmap fname [w] [h] [x] [y] send RGB565 bitmap file 'fname'. w/h/x/y are optional. If w or h is missing then it is assumed 240 If x or y are m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
    [IECDisplay_ST7789.cpp]
2025-09-02 Fixed (unlikely) issue when closing printer data file
    [IECPrinter.cpp]
2025-09-02 Instead of having a bitmap take up RAM space in the Pico, dedicate a portion of the display to the image (never gets cleared or overwritten).
    When mounting a disk image NAME.D64, if a RGB565 bitmap file named 'NAME_WxH.BIN' exists (where W and H are width and height of the bitmap) then display that image.
2025-09-19 Reduced LED brightness on RP2040-One board
2025-09-20 Allow rotating display by setting config value "rotate" to 0,90,180 or 270. If config value "fsformat" is set to "1" then the LittleFS filesystem will be re-formatted at the next reboot. Moved displa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
    [IECDisplay_ST7789.cpp]
2025-09-21 Fixed location of print "animation"
    [IECDisplay_ST7789.cpp]
2025-09-28 LOADing a disk image file mounts the disk image and loads its directory. LOADing ".." or "/" while a disk image is mounted unmounts the image and loads the SD card directory.
2025-10-09 New parameter "diskflush" controls the timing of when changes in a disk image are written back to the disk image file on LittleFS: - diskflush<0: changes are only written back when disk image is unmo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
2025-10-10 Reorganized code for flushing disk cache after writes. Now waits until drive is completely inactive (instead of just no more writes). Fixed issue where drive LED would stay on in some cases. Added "s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
    [IECDrive.cpp]
2025-10-11 Fixed Epyx block read/write operations. Support setting disk address via M-W
    [IECDrive.cpp]
2025-10-11 Fixed issue with B-P command
    [IECDrive.cpp]
2025-10-11 Fixed buffering issue with U1 and B-R commands
    [IECDrive.cpp]
2025-10-12 Show error message if a "M-E" (memory execute) command is received (not supported). Close current file and update display when "I" command is received.
    [IECDrive.cpp]
2025-10-13 Support DolphinDos 40 track D64/G64 images (read and write). Fixed some issues with "V" command.
2025-11-24 If PIN_IEC_CLK_OUT and PIN_IEC_DATA_OUT are defined then use inverted inputs and outputs (latest board revision usies 7406 for outputs and 74LVC04 for inputs)
2025-12-14 Immediately apply new "display rotation" setting without requiring reboot
    [IECDisplay_ST7789.cpp]
2025-12-18 Immediately apply display rotation setting when issued as "CFG:ROTATE=..." through disk command channel.
    [IECDrive.cpp]
2025-12-21 Code cleanup and file naming fixes
    [Pins.h, SKDisplay_ST7789.cpp]
2026-01-11 Added KiCad files
    [IECBuddy-max.kicad_pcb, IECBuddy-max.kicad_sch, IECBuddy-micro.kicad_pcb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]
2026-01-12 More work on README
    Added links for compatible parallel cable descriptions.
2026-01-14 Added Gerber and Schematic files
2026-01-14 More work on README
    Updated links for Gerber files, schematics, and KiCad files for PCB production in the README.
2026-03-17 Fixed "XF-" and "XF+" (disable/enable burst transfer mode) support in DolphinDos
    [IECFileDevice.cpp]
2026-03-25 Correct capacitor values in component list

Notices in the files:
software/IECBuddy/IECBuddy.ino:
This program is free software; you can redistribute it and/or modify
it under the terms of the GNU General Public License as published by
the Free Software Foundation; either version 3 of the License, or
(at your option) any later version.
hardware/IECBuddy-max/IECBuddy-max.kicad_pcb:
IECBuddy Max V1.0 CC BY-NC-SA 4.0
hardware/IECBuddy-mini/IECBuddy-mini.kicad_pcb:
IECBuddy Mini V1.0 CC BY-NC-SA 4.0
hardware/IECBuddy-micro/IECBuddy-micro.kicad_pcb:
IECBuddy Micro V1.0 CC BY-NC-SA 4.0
